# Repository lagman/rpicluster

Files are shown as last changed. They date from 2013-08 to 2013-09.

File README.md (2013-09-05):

RPiCluster Repository
========================================================================================
8-13-2013

Joshua Kiepert  
Boise State University  
Department of Electrical and Computer Engineering  
joshkiepert@boisestate.edu

Overview
----------------------------------------------------------------------------------------
The RPiCluster project was started in Spring 2013 in response to a need during my PhD
dissertation research. My research is currently focused on developing a novel data sharing system
for wireless sensor networks to facilitate in-network collaborative processing of sensor data. 
In the process of developing this system it became clear that perhaps the most expedient way to 
test many of the ideas was to create a distributed simulation rather than developing directly 
on the final target embedded hardware. Thus, I began developing a distributed simulation in which 
each simulation node would behave like a wireless sensor node (along with inherent communications 
limitations), and as such, interact with all other simulation nodes within a LAN. This approach 
provided true asynchronous behavior and actual network communication between nodes which enabled 
better emulation of real wireless sensor network behavior.

So, why I would want to build a Beowulf cluster using Raspberry Pis? The Raspberry Pi has a 
relatively slow CPU by modern standards. It has limited RAM, slow USB-based 10/100 Ethernet, and 
its operating system runs directly on a SD card. None of these “features” are ideal for a cluster 
computer! Well, there are several reasons. First, when your dissertation work requires the use of 
a cluster it is nice to ensure that there is one available all the time. Second, RPis provide a 
unique feature in that they have external low-level hardware interfaces for embedded systems use, 
such as I2 C, SPI, UART, and GPIO. This is very useful to electrical engineers (like myself) 
requiring testing of embedded hardware on a large scale. Third, having user-only access to a 
cluster (which is the case for most student-accessible systems) is fine if the cluster has all 
the necessary tools installed. If not however, you must then work with the cluster administrator 
to get things working. Thus, by building my own cluster I could directly outfit it with anything 
I might need. Finally, RPis are cheap! The RPi platform has to be one of the cheapest ways to 
create a cluster of 32 nodes. The cost for an RPi with an 8GB SD card is ~$45. For comparison, 
each node in one of the clusters available to students here at BSU, was about $1,250. So, for not 
much more than the price of one PC-based node, I could create a 32 node Raspberry Pi
cluster!

Update:
While the BeagleBone Black was not available when I started this project, I would have chosen it 
rather than the Raspberry Pi had it been available. It is the same cost once you include an SD 
card, but it has onboard 2GB of flash storage for the operating system. It also uses a 
Cortex-A8 ARM processor running at 1GHz.

This repository contains the EagleCAD v5.x design files, MPI test code, C test code, and
Bash scripts I used for developing and testing the RPiCluster. 

Documentation
-----------------------
+ docs/Creating.a.Raspberry.Pi-Based.Beowulf.Cluster[BSU].pdf  
	Original white paper on the development of the RPiCluster.

+ docs/Creating.a.Raspberry.Pi-Based.Beowulf.Cluster[EEWeb].pdf  
	Shorter article written for EEWeb's Pulse Magazine  
	http://www.eeweb.com/pulse/issue-106-2013

EagleCAD v5.x Resources
-----------------------
+ eagle/power-led  
	PCB layout for RPiCluster power/led boards
+ eagle/case-layout  
	Plexiglas panel layout (panel measurements, hole patterns, etc)

C Resources
-----------------------
+ c/blink  
	C program that utilizes the wiringPi library to drive the RGB LED on the Power/LED board.

MPI Resources
-----------------------
+ mpi/pblink  
	C MPI program that blinks the RGB LEDs in various patterns on the RPiCluster.

Bash Script Resources
-----------------------
+ scripts/cexec  
	Executes a program on multiple machines via SSH
+ scripts/cscp  
	Copies a local file to multiple machines via SSH
+ scripts/cshutdown  
	Powers down multiple machines via SSH
+ scripts/cssh-copy-id  
	Copies SSH identity to multiple machines for passwordless SSH
+ scripts/rgb-blink  
	Blinks the RGB LEDs on the Power/LED board (using file I/O)
+ scripts/rpitemp  
	Gets the RPi's SoC temperature
+ ssh-everywhere.sh  
	Handy script for creating an SSH session on many machines using tmux

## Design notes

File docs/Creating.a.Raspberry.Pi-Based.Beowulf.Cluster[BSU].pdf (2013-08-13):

# Creating a Raspberry Pi-Based Beowulf Cluster

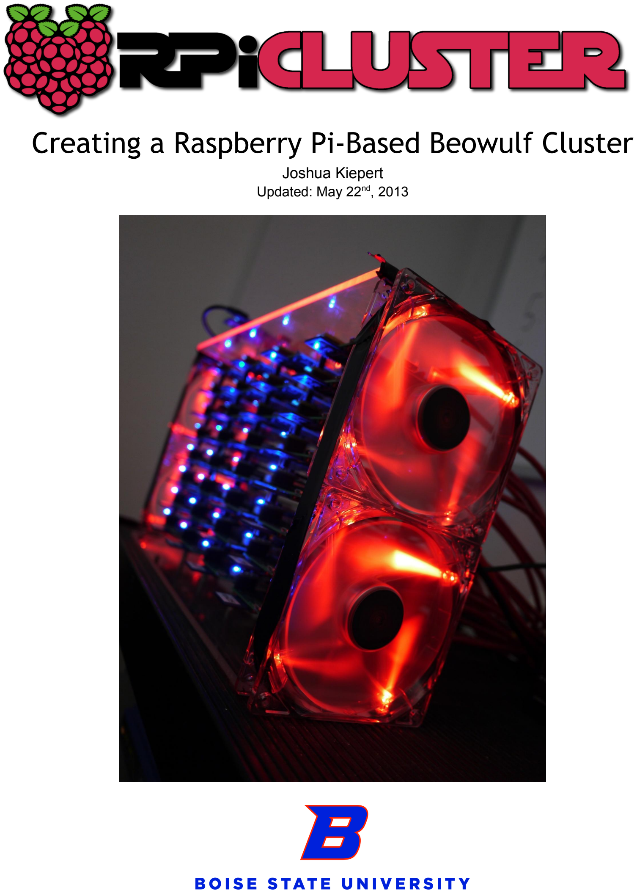
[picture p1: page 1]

Joshua Kiepert
Updated: May 22nd, 2013

## Introduction

Raspberry Pis have really taken the embedded Linux community by storm. For those unfamiliar, however, a Raspberry Pi (RPi) is a small (credit card sized), inexpensive single-board computer that is capable of running Linux and other lightweight operating systems which run on ARM processors. Figure 1 shows a few details on the RPi capabilities.

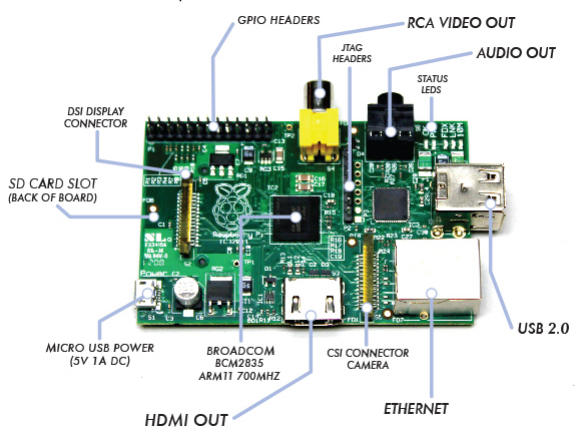
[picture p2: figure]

Figure 1: Raspberry Pi Model B (512MB RAM)

The RPiCluster project was started a couple months ago in response to a need during my PhD dissertation research. My research is currently focused on developing a novel data sharing system for wireless sensor networks to facilitate in-network collaborative processing of sensor data. In the process of developing this system it became clear that perhaps the most expedient way to test many of the ideas was to create a distributed simulation rather than developing directly on the final target embedded hardware. Thus, I began developing a distributed simulation in which each simulation node would behave like a wireless sensor node (along with inherent communications limitations), and as such, interact with all other simulation nodes within a LAN. This approach provided true asynchronous behavior and actual network communication between nodes which enabled better emulation of real wireless sensor network behavior.

For those who may not have heard of a Beowulf cluster before, a Beowulf cluster is simply a collection of identical, (typically) commodity computer hardware based systems, networked together and running some kind of parallel processing software that allows each node in the cluster to share data and computation. Typically, the parallel programming software is MPI (Message Passing Interface), which utilizes TCP/IP along with some libraries to allow programmers to create parallel programs that can split a task into parts suitable to run on multiple machines simultaneously. MPI provides an API that enables both asynchronous and synchronous process interaction. While my simulation did not necessarily need a Beowulf cluster, since it simply required a number of computers on a common network, a cluster environment provided a very convenient development platform for my project thanks to its common file system and uniform hardware.

Here at Boise State University we have such a cluster in the “MetaGeek Lab” (or Onyx Lab), which is run by the Computer Science Department. The Onyx cluster currently utilizes 32 nodes, each of which has an 3.1GHz Intel Xeon E3-1225 quad-core processor and 8GB of RAM. Clearly, this setup has the potential to offer quite good performance for parallel processing.

So, with Onyx available to me, you may ask why I would build a Beowulf cluster using Raspberry Pis? Well, there are several reasons. First, while the Onyx cluster has an excellent uptime rating, it could be taken down for any number of reasons. When you have a project that requires the use of such a cluster and Onyx is unavailable, there are not really any other options on campus available to students aside from waiting for it to become available again. The RPiCluster provides another option for continuing development of projects that require MPI or Java in a cluster environment. Second, RPis provide a unique feature in that they have external low-level hardware interfaces for embedded systems use, such as I²C, SPI, UART, and GPIO. This is very useful to electrical engineers requiring testing of embedded hardware on a large scale. Third, having user only access to a cluster is fine if the cluster has all the necessary tools installed. If not however, you must then work with the cluster administrator to get things working. Thus, by building my own cluster I could outfit it with anything I might need directly. Finally, RPis are cheap! The RPi platform has to be one of the cheapest ways to create a cluster of 32 nodes. The cost for an RPi with an 8GB SD card is ~$45. For comparison, each node in the Onyx cluster was somewhere between $1,000 and $1,500. So, for near the price of one PC-based node, we can create a 32 node Raspberry Pi cluster!

Although an inexpensive bill of materials looks great on paper, cheaper parts come with their own set of downsides. Perhaps the biggest downside is that an RPi is no where near as powerful as a current x86 PC. The RPi has a single-core ARM1176 (ARMv6) processor, running at 700MHz (though overclocking is supported). Additionally, since the RPi uses an ARM processor, it has a different architecture than PCs, i.e. ARM vs x86. Thus, any MPI program created originally on x86 must be recompiled when deployed to the RPiCluster. Fortunately, this issue is not present for java, python, or perl programs. Finally, because of the limited processing capability, the RPiCluster will not support multiple users simultaneously using the system very well. As such, it would be necessary to create some kind of time-sharing system for access if it ever needed to be used in such a capacity.

The overall value proposition is pretty good, particularly if cluster program development is focused on distributed computing rather than parallel processing. That is, if the programs being developed for the cluster are distributed in nature, but not terribly CPU intensive. Compute-intensive applications will need to look elsewhere, as there simply is not enough “horse power” available to make the RPi a terribly useful choice for cluster computing.

## Building the System

There are really only five major components needed for a working cluster: computer hardware, Linux OS, an MPI library, an ethernet switch, and possibly a router. Of course, we have already chosen the

RPi as the computer hardware. Figure 2 (a) shows the overall network architecture. The system design includes 32 RPi nodes, 48-port 10/100 switch, Arch Linux ARM, and MPICH3. The bill of materials can be seen in Figure 2 (b).

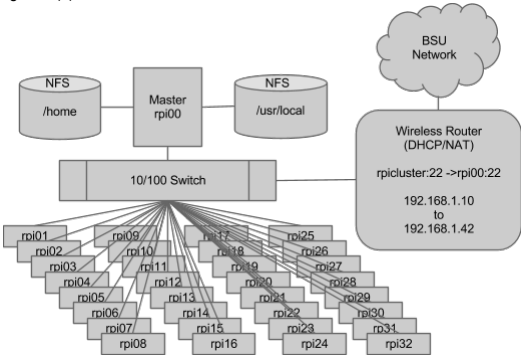
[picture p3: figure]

(a) RPiCluster Network Architecture

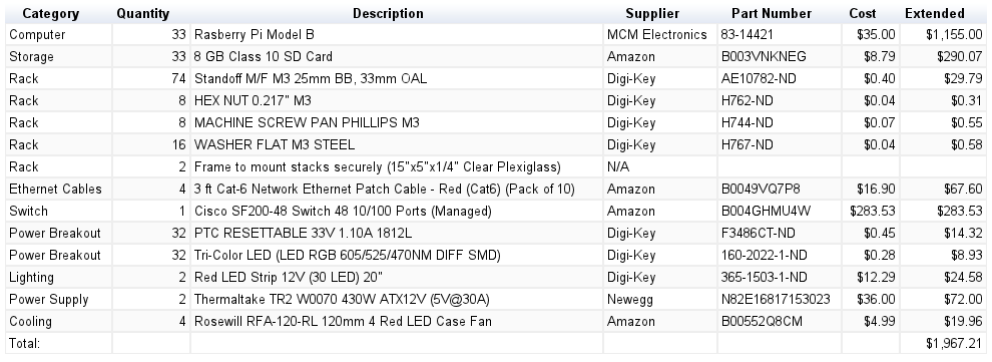
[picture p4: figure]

(b) Bill of Materials
Figure 2: Cluster Design

There are several operating systems available as pre-configured Linux images for the RPi: Raspbian “wheezy” (based on Ubuntu 11.10) and Arch Linux for ARM (aka “alarm”) ( raspberrypi (http://www.raspberrypi.org/downloads). (http://www.raspberrypi.org/downloads) org). (http://www.raspberrypi.org/downloads) Raspbian is available in both hard and soft float versions. “Hard-float” implies it is compiled with support for the hardware floating-point unit in the ARM processor, whereas soft-float implies it will use software libraries to implement floating-point operations. Clearly, hard float is desirable for performance, but for compatibility reasons soft-float is available. In the case of Raspbian, hard-float is not yet supported by

Oracle’s Java Development Kit (JDK)/Java Virtual Machine (JVM) for ARM. It is worth noting that the Oracle JDK is not the only Java implementation available, so there is no need to limit performance with soft-float. The beauty of open source is that you can simply compile the program for your platform even if the vendor has not taken the time to do so. In this case, OpenJDK (http://openjdk.java.net/) is the open source implementation of Java, and it is available on all Linux distributions, including Raspbian and Arch. Arch LInux for ARM is only available in the hard-float configuration.

So, which Linux distribution makes sense for a cluster of RPis? This depends greatly on how comfortable you are with Linux. Raspbian provides a turnkey solution in that it comes pre-installed with the LXDE (a full desktop environment), and being Debian based, there is a huge set of packages precompiled and available for the RPi. This is great for getting started with Linux and with the RPi in general. The downside to this distribution is its weight. With support for so many features to begin with, there is a staggering amount of daemons running all the time. As such, boot time is much longer than it has to be, and you have many packages installed that you most likely will never need or use.

Arch LInux on the other hand, takes the minimalist approach. The image is tiny at ~150MB. It boots in around 10 seconds. The install image has nothing extra included. The default installation provides a bare bones, minimal environment, that boots to a command line interface (CLI) with network support. The beauty of this approach is that you can start with the cleanest, fastest setup and only add the things you need for your application. The downside is you have to be willing to wade through the learning process of a different (but elegant) approach to Linux, which is found in Arch Linux. Fortunately, Arch Linux has some of the best organized information out there for learning Linux. An excellent place to start is the Arch (https://wiki.archlinux.org/index.php/Beginners'_Guide) Linux (https://wiki.archlinux.org/index.php/Beginners'_Guide) Beginner (https://wiki.archlinux.org/index.php/Beginners'_Guide)’ (https://wiki.archlinux.org/index.php/Beginners'_Guide) s (https://wiki.archlinux.org/index.php/Beginners'_Guide) Guide. (https://wiki.archlinux.org/index.php/Beginners'_Guide) I could go on about all the things I appreciate about Arch Linux, but I digress. As you might have guessed from my previous statements, and being a “Linux guy” myself (Linux Mint, primarily), I chose Arch Linux for the RPiCluster.

As for the MPI implementation, I chose MPICH primarily due to my previous familiarity with it through Parallel Computing classes (OpenMPI is available also). If you are running Raspbian, MPI can be installed by executing something like:

$ sudo apt-get install mpich2

That’s it. However, on Arch Linux MPICH must be compiled from source, or installed from the AUR database. I did some looking on AUR, and only found an older version of MPICH (built for an old version of gcc). So, I went with the compile-from-source method. You can get the source from mpich (http://www.mpich.org/downloads/). (http://www.mpich.org/downloads/) org. (http://www.mpich.org/downloads/) OpenMPI is available in the Arch Linux repositories, and it can be installed as follows:

$ sudo pacman -Syy openmpi

In the case of MPICH, compiling large amounts of source on a 700MHz machine can be tedious. So, why not utilize our Core i7 Quad-Core to do the job? Enter: QEMU. QEMU (http://en.wikibooks.org/wiki/QEMU) is a CPU architecture emulator and virtualization tool. It so happens that it is capable of emulating an ARM architecture very similar to the RPi. This allows us to boot an RPi image directly on our x86 or x86_64 system! There is one caveat, you need an RPI kernel for QEMU that knows how to deal with the QEMU virtualized hardware which is not normally part of the RPi kernel image. This involves downloading the Linux kernel source, applying a patch to support the RPi, adding the various kernel features and drivers needed, and compiling. The compile process for the kernel only took about 5 minutes on my i7 laptop. Downloading the source from the Git repository, however, took much longer (~1.5GB).

There are several tutorials available which provide details for running QEMU with an RPI system image. A couple references I found useful are Raspberry (http://www.v13.gr/blog/?p=276) Pi (http://www.v13.gr/blog/?p=276) under (http://www.v13.gr/blog/?p=276) QEMU (http://www.v13.gr/blog/?p=276) and Raspberry (http://ebalaskas.gr/blog/2013/03/25/raspberry-pi-with-archlinux-under-qemu/) Pi (http://ebalaskas.gr/blog/2013/03/25/raspberry-pi-with-archlinux-under-qemu/) with Archlinux (http://ebalaskas.gr/blog/2013/03/25/raspberry-pi-with-archlinux-under-qemu/) under (http://ebalaskas.gr/blog/2013/03/25/raspberry-pi-with-archlinux-under-qemu/) QEMU. (http://ebalaskas.gr/blog/2013/03/25/raspberry-pi-with-archlinux-under-qemu/) Aside from the need for a custom kernel, there are a couple system configuration changes needed within the RPi image to allow it to boot flawlessly. The changes primarily have to do with the fact that the RPi images assume the root file system is on /dev/mmcblk0p2 and the boot partition is on /dev/mmcblk0p1. QEMU makes no such assumptions so you have to map /dev/sda devices to mmcblk0 devices on boot. With the RPi system image adjusted and the custom kernel built, starting QEMU is something like the following:

$ qemu-system-arm -kernel ./zImage -cpu arm1176 -m 256 -M versatilepb -no-reboot -serial stdio -append "root=/dev/sda2 panic=0 rw" -hda archlinux-hf-2013-02-11.img

Once you have a kernel image (zImage) that is suitable for QEMU you can point it at the new kernel and the RPi system image. Running an RPi image via QEMU may be significantly faster than working on the RPi, of course, this depends on the computer being used to run QEMU. Figure 3 shows the boot screen of Arch Linux ARM under QEMU.

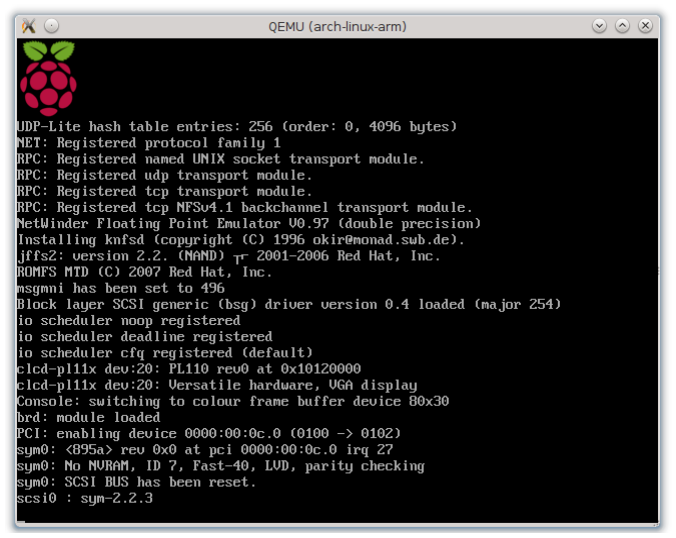
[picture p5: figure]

Figure 3: Arch Linux ARM under QEMU

With a working Arch Linux image under QEMU it is possible to update to the latest packages, install the necessary packages for the cluster environment, and compile MPICH for parallel computing, all from the comfort of you x86 Linux system. I used QEMU for all of the aforementioned tasks. Once configuration of the image was completed with QEMU, I was able to simply write the resulting image to each RPi SD card (after modifying hostname and IP address, unique to each).

Below are a few of the steps involved for configuring an Arch Linux image for use in a cluster:

Change root password from default (root):
# passwd

Full system update:
# pacman -Syyu

Install typically needed packages, bold packages are need for compiling MPICH and for using NFS or OpenMPI:
# pacman -S nfs-utils | base-devel | openmpi | sudo | adduser | nano vim | gdb | bc | minicom

Set | the | local | timezone:
# | timedatectl | set-timezone | | America/Boise

Adds a new user...<user> in this case (be sure to add groups wheel,audio,video,uucp when prompted):
# | adduser | <user>

Allow users that are part of the wheel group to use superuser permissions:
# | chmod | 600 /etc/sudoers

# | nano | /etc/sudoers

(Uncomment the line: %wheel = ... and save)

# logout

(Login as user who will be using MPI)
$ | ssh-keygen | -t | rsa
$ | ssh-keygen | -t | dsa
$ | ssh-keygen | -t | edsa

Cluster setup is basically just configuring a few files so that all nodes can find each other and have password-less SSH access to one another.

Key configuration files for cluster setup under Arch Linux:
/etc/exports
/etc/idmapd.conf
/etc/hosts
/etc/hostname
/etc/fstab
/etc/network.d/ethernet-static /etc/conf.d/netcfg

## Performance Comparison

Initially, I created a four-node test platform with RPis. So, it was possible to do some preliminary testing of performance before creating the full cluster. The first test was to determine the general performance of a single node running multiple threads, using the MPI libraries.

The MPI test program I used is one I developed during a parallel computing class at BSU. The program calculates pi using the Monte (http://en.wikipedia.org/wiki/Pi#Geometry_and_trigonometry) Carlo (http://en.wikipedia.org/wiki/Pi#Geometry_and_trigonometry) method. In this method, essentially the more random numbers you generate, the more accurate your resulting estimation of pi. It is an embarrassingly parallel way to calculate pi (i.e., scales easily to multiple independent processes, near 100% performance gain for each additional process added). All that is needed is a way to parallelize the generation of random numbers so that each process does not repeat the random sequence (remember, we are dealing with pseudorandom numbers here). In this case, I use a library called prand, (http://cs.boisestate.edu/~amit/research/prand/) developed by Dr. Jain and Jason Main at BSU.

Table 1 shows the hardware specifications of the various platforms tested for comparison.

Table 1: Test Hardware Specifications

Figure 4 shows the execution time for 900 Million iterations of the Monte Carlo pi calculation program (PMCPI).

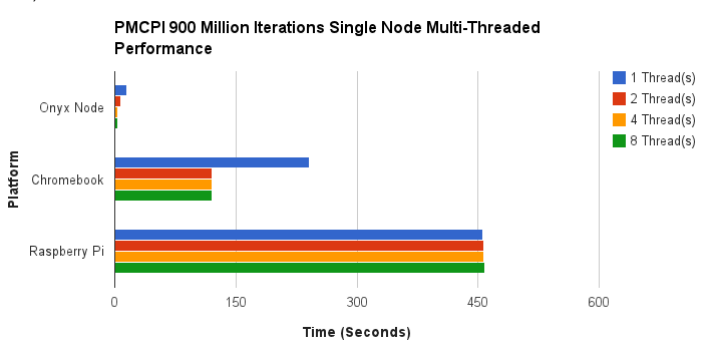
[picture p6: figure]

Figure 4: MPI Single Node Performance¹

1 This is running the MPI program on a single node with multiple threads, not in parallel with other nodes in a cluster.

If you can not tell from Figure 4, that is a maximum of 14.6 seconds for a single thread on an Onyx node. With four threads it goes down to 3.85 seconds thanks to four processing cores. With eight threads, it goes up to 3.90 seconds. Compare that to our lowly RPi, which requires 456 seconds for single thread. Additional threads do not help due to its single core design.

Figures 5 and 6 show the performance improvement as we add additional RPi nodes to participate in the calculation, in execution time and speed up, respectively.

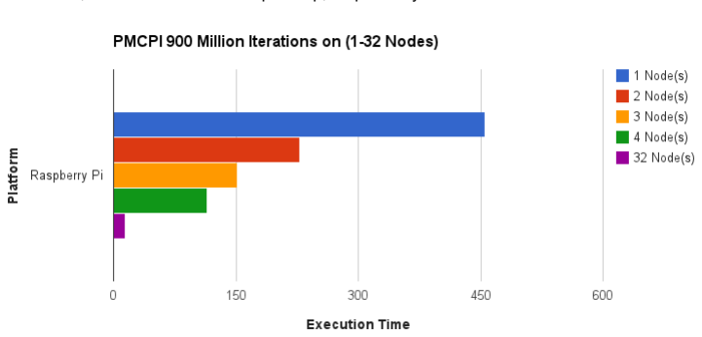
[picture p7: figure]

Figure 5: Execution Time Reduction (1-32 nodes)

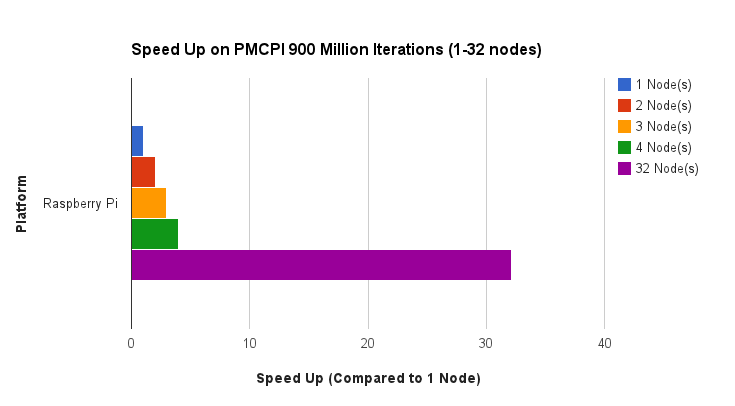
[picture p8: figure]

Figure 6: Speed-Up as Compared to 1 Node

As is seen in Figures 5 and 6, we clearly get the expected performance improvement as we add additional nodes to participate in the calculations.

## Rack and Power Design

One aspect of the cluster design that required quite a lot of thought was the rack mounting system and power distribution method. In order to keep the cluster size to a minimum while maintaining ease of access, the RPis were stacked in groups of eight using PCB-to-PCB standoffs with enough room in between them for a reasonable amount of air flow and component clearance. This configuration suited our needs for power distribution very well since it allowed for a power line to be passed vertically along each stack. Using this orientation, four RPi stacks were assembled and mounted between two pieces of ¼” acrylic. This created a solid structure in which the cluster could be housed and maintain physical stability under the combined weight of 32 Ethernet cables. Figure 7 (a) shows some initial experimentation using this method of mounting. The plexiglass layout for mounting each RPi stack was designed using EagleCAD, along with the power/LED PCB. Figure 7 (b) shows the layout.

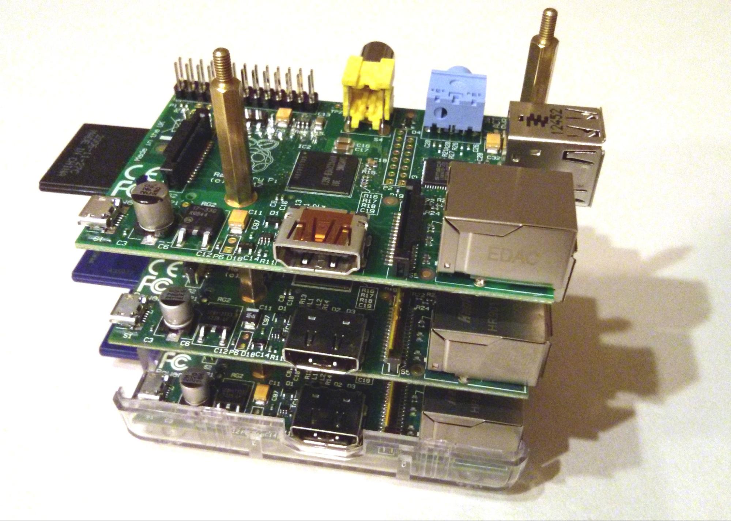
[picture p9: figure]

(a) Rack Mounting RPis Using PCB Stand-offs

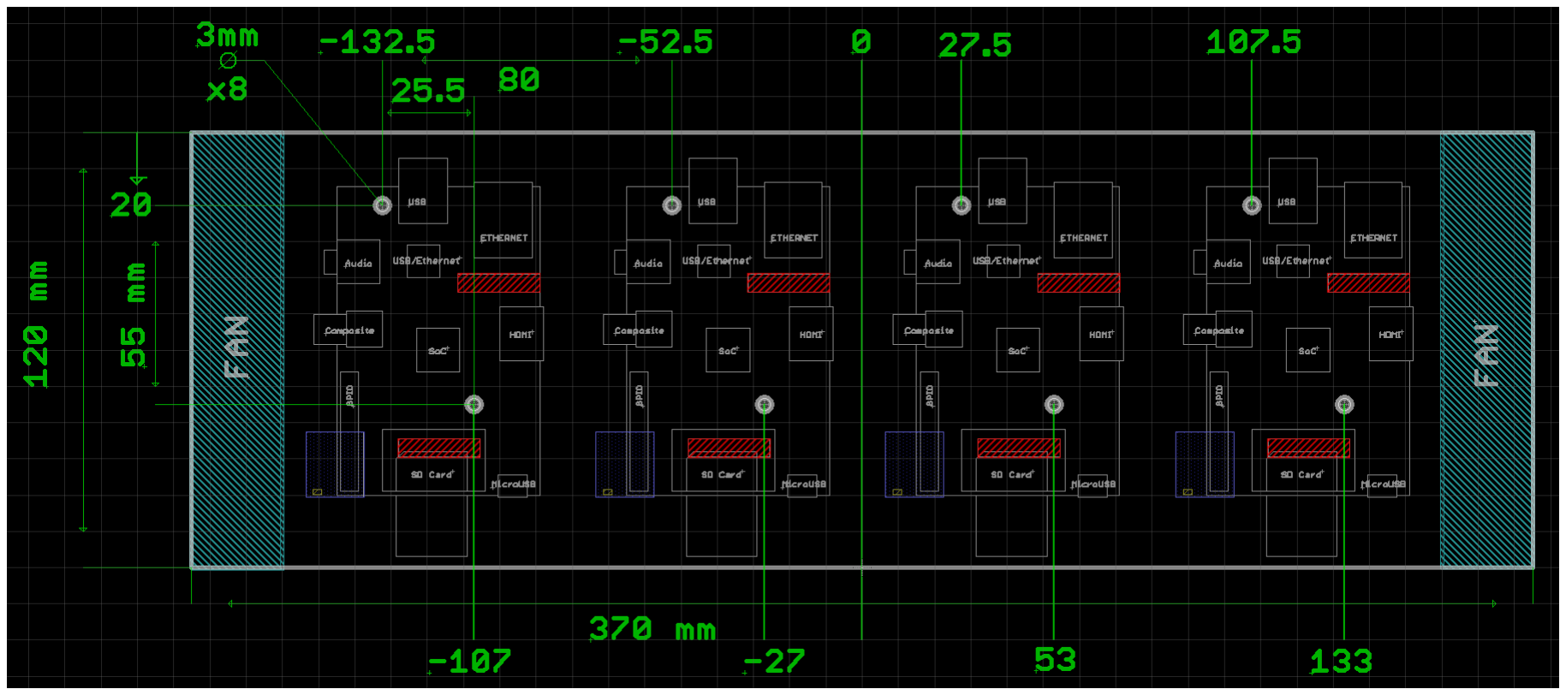
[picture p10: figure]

(b) Plexiglass Layout (Top/Bottom of RPiCluster Rack) Figure 7: RPiCluster Rack Components

There are two methods of powering an RPi. Each RPi has a microUSB port that enables it to be powered from a conventional powered USB port. Using this method would require a microUSB cable and a powered USB port for every RPi in the cluster, which would add a lot more cabling to deal with. It also means that there would be cabling on both sides of the cluster. Alternatively, there is an I/O header on the side of the RPi which contains a 5V pin that can be used to power the board externally. The latter option was chosen as it would also allow for additional customization and control of each node. A custom PCB was created to fit the I/O header to provide power and an RGB LED (since electrical engineers must, of course, have LEDs to show that their project is working). Figure 8 (a) and (b) show the circuit and PCB layouts, respectively.

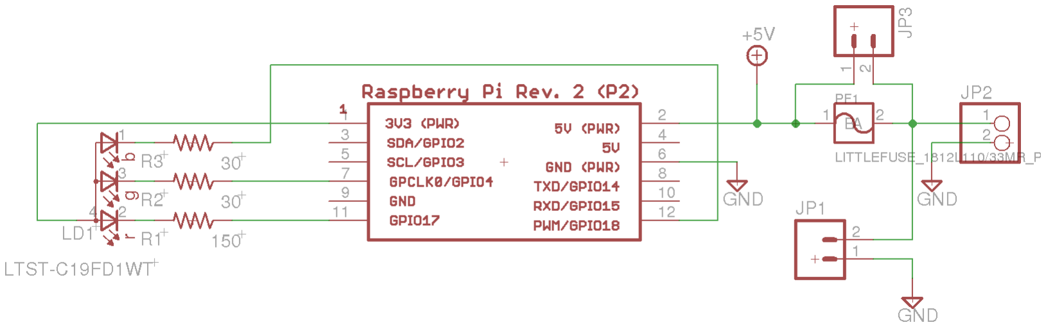
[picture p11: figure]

(a) RPiCluster Power/LED Board Schematic

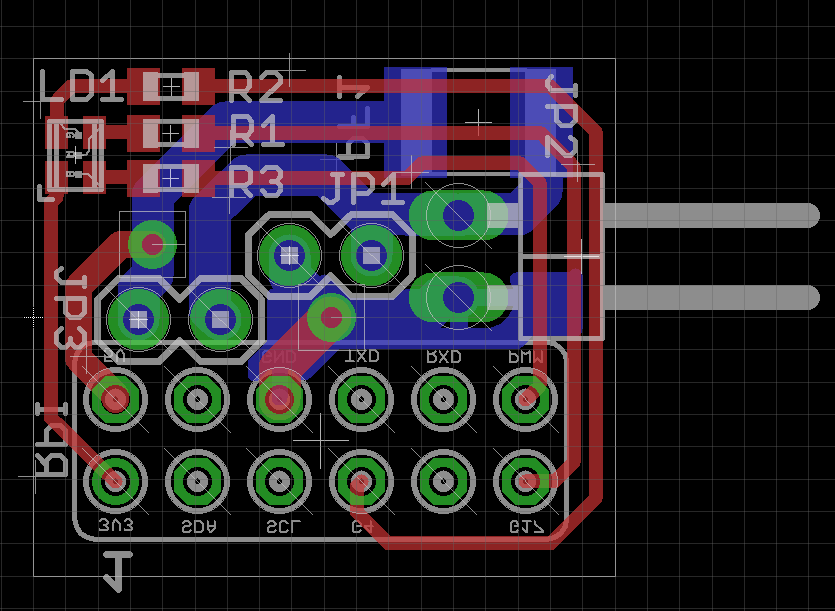
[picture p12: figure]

(b) RPiCluster Power/LED Board PCB Layout Figure 8: RPiCluster Power/LED Board

As seen in Figure 8 (a), aside from a RGB LED and some connectors, there is also a poly fuse (PF1). This was included to maintain short-circuit protection in the event of a board failure. The RPi already has a poly fuse between the USB power connector and the 5V rail. That fuse is bypassed when using the 5V pin to power the board. JP1 provides a 5V interconnect vertically between the RPis in each stack.

With the power being directly distributed via the Power/LED board, it was necessary to find a good source of 5V with sufficient amperage to drive the whole cluster. Each RPi draws about 400mA at 5V (2W), thus we needed a minimum of 13A of 5V (65W) (and more for overclocking). You could, of course, buy a dedicated high output 5V power supply, but a great option is to use a standard PC power supply. PC power supplies are already designed for high loads on their 5V rails, and they are relatively cheap. The 430W Thermaltake (430W combined output for 5V, 12V, etc) we selected is rated to provide 30A at 5V (150W) and cost $36. We opted to purchase two supplies to keep the overall load very low on each and allow for overclocking or future expansion.

## Final Tweaks

As mentioned earlier, the RPi processor supports overclocking. Another noteworthy feature is that the 512MB of RAM is shared by both GPU and CPU, and the amount of RAM reserved for the GPU is configurable. Both of these features are configurable through modification of parameters in /boot/config.txt. After some testing, the whole cluster was set to run in “Turbo Mode” which overclocks the ARM core to 1GHz and sets the other clocks (SDRAM etc..) to 500MHz. The result was a proportional increase in performance (~30%) and power draw. Since the cluster does not require a desktop environment, the GPU RAM reserve was reduced to 48MB. 48MB seems to be the smallest amount of RAM allowed for the GPU on the current version of Arch Linux ARM for the RPi (it wouldn’t boot with anything less).

## Power Consumption

One of the great things about creating a cluster with ARM-based processors is low power consumption. As discussed earlier, each RPi uses about 2W of power (when running at 700MHz). A number of power measurements were made at the wall with the RPiCluster in various operational states. This allowed the individual component power usage to be determined without taking each item off-line to measure power draw individually. As I have overclocked the cluster to 1GHz core frequency and 500MHz for SDRAM etc., the power consumption is higher. Figures 9 (a) and (b) show the overall power use (as measured at the wall) in relative proportion (percent) and watts, respectively (overclocked to 1GHz).

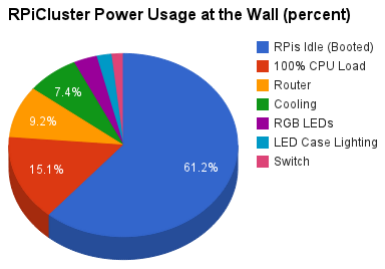
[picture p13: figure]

(a) RPiCluster Component Power Useage (percent)

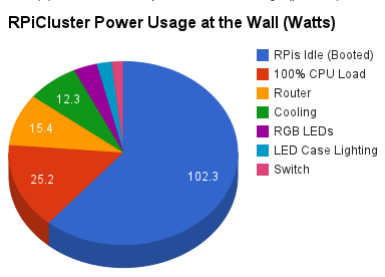
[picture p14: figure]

(b) RPiCluster Component Power Usage (Watts) Figure 9: RPiCluster Power Consumption

As is seen in Figure 9 (b), there is about 15% difference in power consumption between idle and full CPU utilization. Additionally, about 12% of the total power used is attributed to the cooling portion of the cluster (four 120mm fans). The maximum total power usage of the cluster at the wall is about 167

Watts. It is worth noting that active cooling is technically unnecessary. During my testing, the SoC temperature did not exceed 60° C while under 100% load, and the SoC is rated to operate up to 85° C. With cooling active, however, the SoC temperatures did not exceed 35° C. Cooling was retained because it seemed better for the SoC to operate at lower temperatures (and it looks nice).

## Conclusion

Overall, the RPiCluster has proved quite successful. Since completing the build I have moved my dissertation work exclusively to the RPiCluster. I have found performance perfectly acceptable for my simulation needs, and have had the luxury of customizing the cluster software to fit my requirements exactly.

I would like to thank all the guys I work with in the Hartman Systems Integration Laboratory for all their help implementing the cluster design, especially Michael Pook, Vikram Patel, and Corey Warner. Additionally, this project would not have been possible without support from Dr. Sin Ming Loo and the Department of Electrical and Computer Engineering.

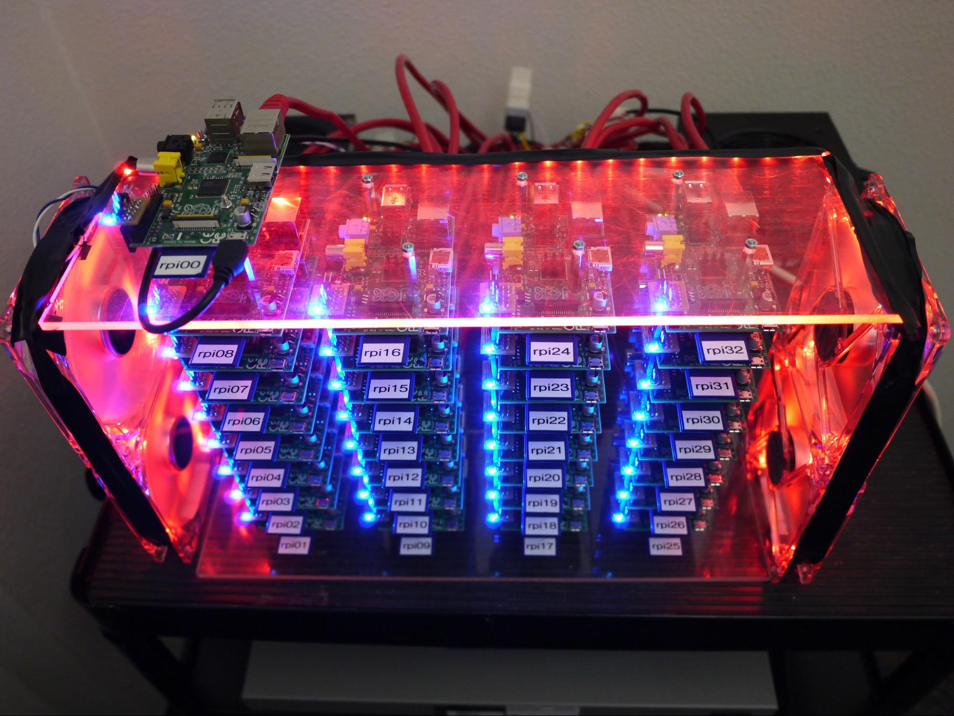
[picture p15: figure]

...and for your viewing pleasure, I have a few more photos:

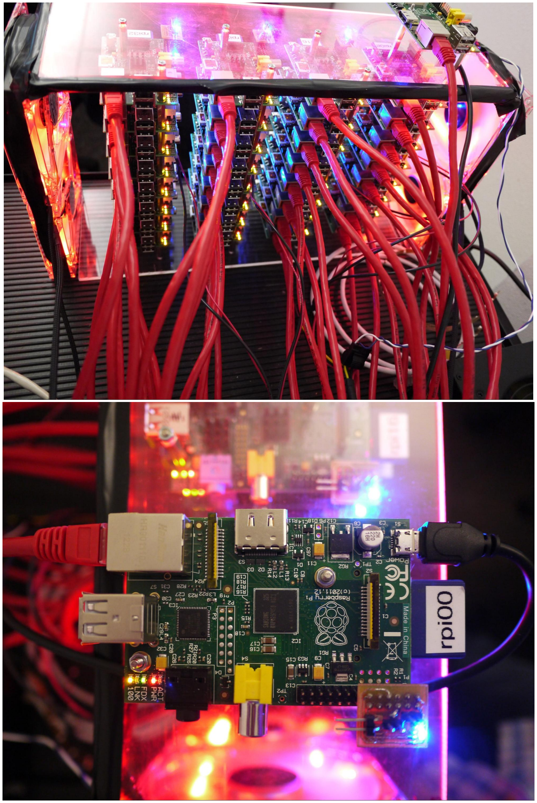
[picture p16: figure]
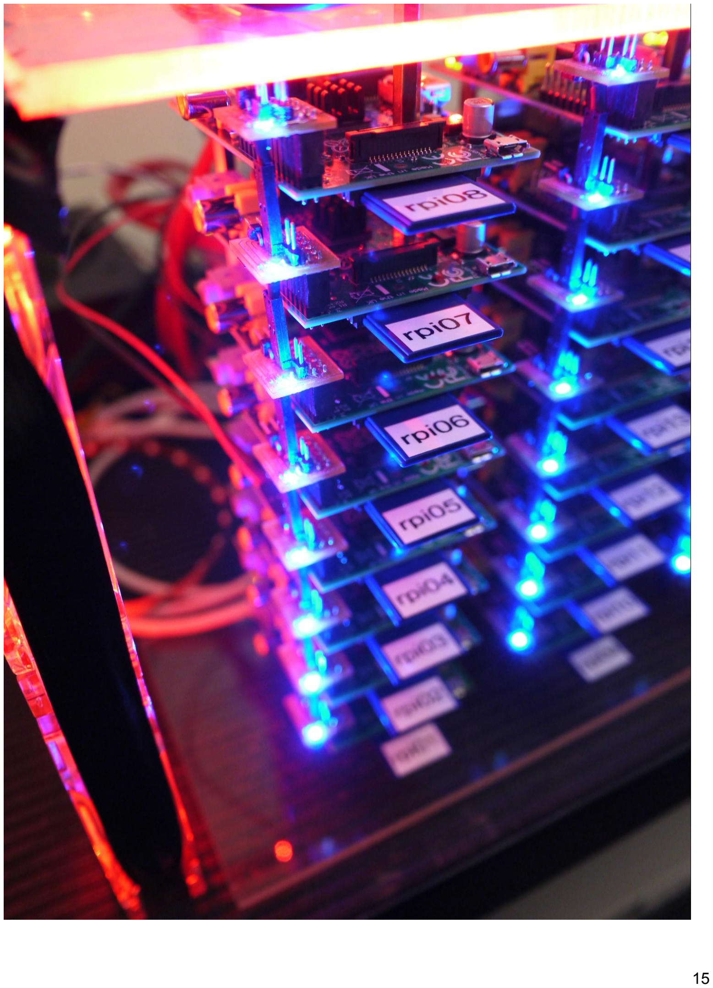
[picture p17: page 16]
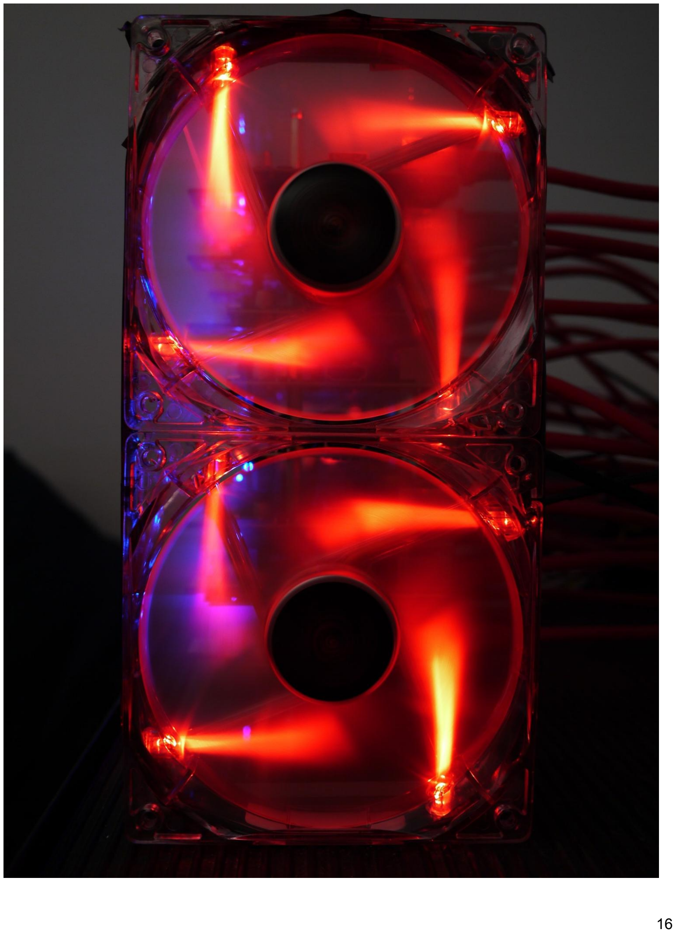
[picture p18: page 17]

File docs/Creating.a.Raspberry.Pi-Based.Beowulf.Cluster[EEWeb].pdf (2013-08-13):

# Creating a Raspberry Pi-Based Beowulf Cluster

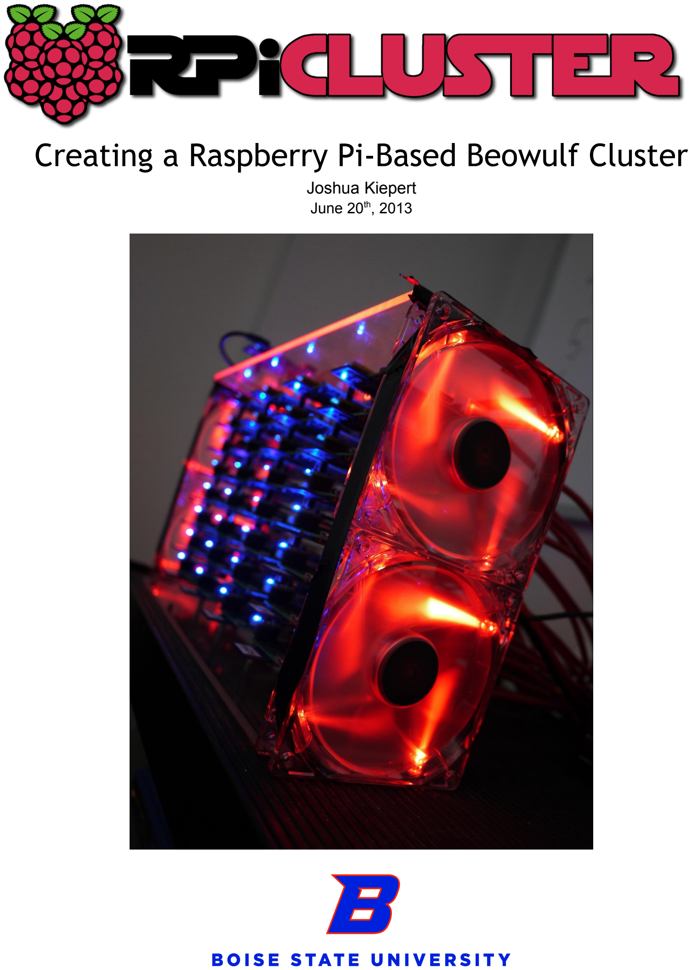
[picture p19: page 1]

Joshua Kiepert
June 20th, 2013

## Introduction

Raspberry Pis have really taken the embedded Linux community by storm. For those unfamiliar, however, a Raspberry Pi (RPi) is a small (credit card sized), inexpensive single-board computer that is capable of running Linux and other lightweight operating systems which run on ARM processors. Figure 1 shows a few details on the RPi's capabilities.
[Figure 1]
The RPiCluster project was started a couple months ago in response to a need during my PhD dissertation research. My research is currently focused on developing a novel data sharing system for wireless sensor networks to facilitate in-network collaborative processing of sensor data. In the process of developing this system it became clear that perhaps the most expedient way to test many of the ideas was to create a distributed simulation rather than developing directly on the final target embedded hardware. Thus, I began developing a distributed simulation in which each simulation node would behave like a wireless sensor node (along with inherent communications limitations), and as such, interact with all other simulation nodes within a LAN. This approach provided true asynchronous behavior and actual network communication between nodes which enabled better emulation of real wireless sensor network behavior.

For those who may not have heard of a Beowulf cluster before, a Beowulf cluster is simply a collection of similar, (typically) commodity computer hardware based systems, networked together and running some kind of parallel processing software that allows each node in the cluster to share data and computation. Typically, the parallel programming software is MPI (Message Passing Interface), which utilizes TCP/IP along with some libraries to allow programmers to create parallel programs that can split a task into parts suitable to run on multiple machines simultaneously. MPI provides an API that enables both asynchronous and synchronous process interaction. My simulation did not require the computational power of a Beowulf cluster; it simply required a many distinct computers on a common network. A cluster environment provided a very convenient development platform for my distributed simulation thanks to its common file system and uniform hardware.

So, why I would want to build a Beowulf cluster using Raspberry Pis? The Raspberry Pi has a relatively slow CPU by modern standards. It has limited RAM, slow USB-based 10/100 Ethernet, and its operating system runs directly on a SD card. None of these “features” are ideal for a cluster computer! Well, there are several reasons. First, when your dissertation work requires the use of a cluster it is nice to ensure that there is one available all the time. Second, RPis provide a unique feature in that they have external low-level hardware interfaces for embedded systems use, such as I²C, SPI, UART, and GPIO. This is very useful to electrical engineers (like myself) requiring testing of embedded hardware on a large scale. Third, having user-only access to a cluster (which is the case for most student-accessible systems) is fine if the cluster has all the necessary tools installed. If not however, you must then work with the cluster administrator to get things working. Thus, by building my own cluster I could directly outfit it with anything I might need. Finally, RPis are cheap! The RPi platform has to be one of the cheapest ways to create a cluster of 32 nodes. The cost for an RPi with an 8GB SD card is ~$45. For comparison, each node in one of the clusters available to students here at BSU, was about $1,250. So, for not much more than the price of one PC-based node, I could create a 32 node Raspberry Pi cluster!

One thing to keep in mind when building a cluster with RPis is to set expectations of performance appropriately. That is, we cannot expect the compute performance to be very good, even when compared to a single modern multi-core desktop computer. This was not a problem for my application because I just needed many independent processors running on a common network to run my distributed application. I didn't need a platform for high performance computing (HPC). Additionally, since the RPi uses an ARM processor, it has a different architecture than PCs, i.e. ARM vs x86. Thus, any MPI program created originally on x86 must be recompiled when deployed to the RPiCluster. Fortunately, this issue is not present for Java, Python, or Perl programs. Finally, because of the limited processing capability, the RPiCluster will not support multiple users simultaneously using the system very well. As such, it would be necessary to create some kind of time-sharing system for access if it ever needed to be used in such a capacity.

In summary, the RPiCluster is great if your development is focused only on distributed computing/network programming rather than parallel processing. That is, if the programs being developed for the cluster are distributed in nature, but not terribly CPU intensive. Compute-intensive applications will need to look elsewhere, as there simply is not enough “horse power” available to make the RPi a terribly useful choice for cluster computing. Of course, even compute-intensive applications could be tested on a small scale with the RPiCluster.

## Building the System

There are really only five major components needed for a working cluster: computer hardware, Linux OS, an MPI library, an Ethernet switch, and possibly a router. Figure 2 shows the overall network architecture. The RPiCluster design consists of 32 RPi nodes, a 48-port 10/100 switch, Arch Linux ARM, and MPICH3. The total cost of the system was $1,967.21.
[Figure 2]
There are several operating systems available as pre-configured Linux images for the RPi: Raspbian “wheezy” (based on Debian) and Arch Linux for ARM (aka “alarm”) ( raspberrypi (http://www.raspberrypi.org/downloads). (http://www.raspberrypi.org/downloads) org). (http://www.raspberrypi.org/downloads) I chose to use Arch Linux for the RPiCluster. Arch Linux was chosen primarily for its minimalist approach which allowed me to install only what I needed. It also resulted in a system that boots in about 10 seconds. There is definitely a learning curve with Arch Linux, but fortunately it has some of the best organized information out there for learning Linux. An excellent place to start is the Arch (https://wiki.archlinux.org/index.php/Beginners'_Guide) Linux (https://wiki.archlinux.org/index.php/Beginners'_Guide) Beginner (https://wiki.archlinux.org/index.php/Beginners'_Guide)’ (https://wiki.archlinux.org/index.php/Beginners'_Guide) s (https://wiki.archlinux.org/index.php/Beginners'_Guide) Guide. (https://wiki.archlinux.org/index.php/Beginners'_Guide)

As for an MPI implementation, I chose MPICH primarily due to my previous familiarity with it (OpenMPI is also available). On Arch Linux MPICH must be compiled from source, or installed from the Arch User Repository (AUR). I went with the compile-from-source method. You can get the source from
mpich (http://www.mpich.org/downloads/). (http://www.mpich.org/downloads/) org. (http://www.mpich.org/downloads/) OpenMPI is available directly in the Arch Linux extra repository.

One thing I found helpful when creating an Arch Linux image for the RPiCluster was QEMU. QEMU (http://en.wikibooks.org/wiki/QEMU) is a CPU architecture emulator and virtualization tool. It is capable of emulating an ARM architecture similar to the RPi. This allows us to boot an RPi image directly on our x86 system. There is one caveat: you need an RPI kernel for QEMU that knows how to deal with the QEMU virtualized hardware, which is not normally part of the RPi kernel image. This involves downloading the Linux kernel source, applying a patch to support the RPi, adding the various kernel features and drivers needed, and compiling.

There are several tutorials available which provide details for running QEMU with an RPI system image. A couple references I found useful are Raspberry (http://www.v13.gr/blog/?p=276) Pi (http://www.v13.gr/blog/?p=276) under (http://www.v13.gr/blog/?p=276) QEMU (http://www.v13.gr/blog/?p=276) and Raspberry (http://ebalaskas.gr/blog/2013/03/25/raspberry-pi-with-archlinux-under-qemu/) Pi (http://ebalaskas.gr/blog/2013/03/25/raspberry-pi-with-archlinux-under-qemu/) with (http://ebalaskas.gr/blog/2013/03/25/raspberry-pi-with-archlinux-under-qemu/)

Archlinux (http://ebalaskas.gr/blog/2013/03/25/raspberry-pi-with-archlinux-under-qemu/) under (http://ebalaskas.gr/blog/2013/03/25/raspberry-pi-with-archlinux-under-qemu/) QEMU. (http://ebalaskas.gr/blog/2013/03/25/raspberry-pi-with-archlinux-under-qemu/) Aside from the need for a custom kernel, there are a couple system configuration changes needed within the RPi image to allow it to boot flawlessly. The changes primarily have to do with the fact that RPi images assume the root file system is on /dev/mmcblk0p2 and the boot partition is on /dev/mmcblk0p1. QEMU makes no such assumptions so you have to map /dev/sda devices to mmcblk0 devices on boot. With the RPi system image adjusted and the custom kernel built, starting QEMU is something like the following:

$ qemu-system-arm -kernel ./zImage -cpu arm1176 -m 256 -M versatilepb -no-reboot -serial stdio -append "root=/dev/sda2 panic=0 rw" -hda archlinux-hf-2013-02-11.img

Once you have a kernel image (zImage) that is suitable for QEMU you can point it at the new kernel and the RPi system image. Figure 3 shows the boot screen of Arch Linux ARM under QEMU. [Figure 3]
With a working Arch Linux image under QEMU, I applied system updates and installed the necessary packages for the cluster environment. Once configuration of the image was completed with QEMU, I was able to simply write the resulting image to each RPi SD card after modifying host name and static IP address, unique to each (I wrote a bash script to do this).

Below are a few of the steps involved for configuring an Arch Linux image for use in a cluster:

1. Change root password from default (root):
# passwd

2. Full system update:
# pacman -Syyu

3. Install typically needed packages, (bold packages are need for using NFS, OpenMPI, and software development:
# pacman -Syy nfs-utils | base-devel | openmpi | sudo | adduser gdb

4. Set the timezone for your location (<city>):
# timedatectl set-timezone America/<city>

5. Add a new user (<user>) and be sure to add groups wheel, audio, video, and uucp when prompted:
# adduser <user>

6. Allow users that are part of the wheel group to use superuser permissions:
# chmod 600 /etc/sudoers

7. Uncomment the line: %wheel = ... and save:
# nano /etc/sudoers

8. Logout of root and login as the user who will be using MPI and generate ssh keys for password-less login:
$ | ssh-keygen | -t | rsa
$ | ssh-keygen | -t | dsa
$ | ssh-keygen | -t | edsa

Strictly speaking, there is nothing special needed for a working cluster other than MPI and SSH, however a shared file system makes life much easier (e.g. NFS). Cluster setup is basically just configuring a few files so that all nodes can find each other by name on the network and have password-less SSH access to one another. Key configuration files for cluster setup under Arch Linux:

NFS: | /etc/exports
NFS: | /etc/idmapd.conf
NFS: | /etc/fstab
SSH: | /home/<mpiuser>/.ssh/authorized_keys
Network: | /etc/hosts
Network: | /etc/hostname
Network: | /etc/network.d/ethernet-static
Network: | /etc/conf.d/netcfg

For the fine details on NFS, network, and SSH setup, see the Arch Wiki: NFS, (https://wiki.archlinux.org/index.php/NFS) Network, (https://wiki.archlinux.org/index.php/Beginners'_Guide#Static_IP) SSH. (https://wiki.archlinux.org/index.php/SSH_Keys)
Rack and Power Design
One aspect of the cluster design that required quite a lot of thought was the rack mounting system and power distribution method. In order to keep the cluster size to a minimum while maintaining ease of access, the RPis were stacked in groups of eight using PCB-to-PCB standoffs with enough room in between them for a reasonable amount of air flow and component clearance. This configuration suited our needs for power distribution very well since it allowed for a power line to be passed vertically along each stack. Using this orientation, four RPi stacks were assembled and mounted between two pieces of ¼” Plexiglas. This created a solid structure in which the cluster could be housed and maintain physical stability under the combined weight of 32 Ethernet cables. Figure 4 (a) shows some initial experimentation using this method of mounting. The Plexiglas layout for mounting each RPi stack was designed using EagleCAD, along with the power/LED PCB. Figure 4 (b) shows the layout.
| [Figure 4]
There are two methods of powering an RPi. Each RPi has a microUSB port that enables it to be powered from a conventional powered USB port. Using this method would require a microUSB cable and a powered USB port for every RPi in the cluster, which would add a lot more cabling to deal with. It also means that there would be cabling on both sides of the cluster. Alternatively, there is an I/O header on the side of the RPi which contains a 5V pin that can be used to power the board externally. The latter option was chosen as it would also allow for additional customization and control of each node. A custom PCB was created to fit the I/O header to provide power and an RGB LED (since electrical engineers must, of course, have LEDs to show that their project is working). Figure 5 (a) and (b) show the circuit and PCB layouts, respectively.
| [Figure 5]
As seen in Figure 5 (a), aside from a RGB LED and some connectors, there is also a poly fuse (PF1). This was included to maintain short-circuit protection in the event of a board failure. The RPi already has a poly fuse between the USB power connector and the 5V rail. That fuse is bypassed when using the 5V pin to power the board. JP1 provides a 5V interconnect vertically between the RPis in each stack.

With the power being directly distributed via the Power/LED board, it was necessary to find a good source of 5V with sufficient amperage to drive the whole cluster. Each RPi draws about 400mA at 5V (2W), thus we needed a minimum of 13A of 5V (65W) (and more for overclocking). You could, of course, buy a dedicated high output 5V power supply, but a great option is to use a standard PC power supply. PC power supplies are already designed for high loads on their 5V rails, and they are relatively cheap. The 430W Thermaltake (430W combined output for 5V, 12V, etc) we selected is rated to provide 30A at 5V (150W) and cost $36. We opted to purchase two supplies to keep the overall load very low on each and allow for overclocking or future expansion.

## Final Tweaks

As mentioned earlier, the RPi processor supports overclocking. Another noteworthy feature is that the 512MB of RAM is shared by both GPU and CPU, and the amount of RAM reserved for the GPU is configurable. Both of these features are configurable through modification of parameters in /boot/config.txt. After some testing, the whole cluster was set to run in “Turbo Mode” which overclocks the ARM core to 1GHz and sets the other clocks (SDRAM etc..) to 500MHz. The result was a proportional increase in performance (~30%) and power draw. Since the cluster does not require a desktop environment, the GPU RAM reserve was reduced to 48MB. 48MB seems to be the smallest amount of RAM allowed for the GPU on the current version of Arch Linux ARM for the RPi (it wouldn’t boot with anything less).

## Performance

As discussed earlier, the RPiCluster was not built with the intent of creating a HPC platform. However, it is still interesting to see where it ended up, right? There are, of course, many methods for measuring the performance of a cluster. Initially, I did some individual CPU tests comparing various platforms with the RPi. Table 1 shows the specifications of the platforms used for comparison. Each platform was compared on the basis of single core/single thread integer/floating point performance using the GNU arbitrary precision calculator: bc.
[Table 1]
Figure 6 shows the performance of each platform, where the performance is measured in terms of how little time was required to complete the calculation (shorter time is better).
[Figure 6]
Of course, after I published some details of the RPiCluster, everyone wanted to know what kind of MPI parallel performance the RPiCluster has. So, I took some time to get HPL (http://www.netlib.org/benchmark/hpl/index.html) (often used for the TOP500 (http://www.top500.org/) list) working on the RPiCluster to determine overall parallel computing performance. For comparison, I also setup HPL on a single Onyx node (multi-threaded to leverage all the cores). Table 2 shows the resources available and the HPL results after being tuned for peak performance on both platforms. [Table 2]
As is seen in Table 2, the RPiCluster HPL performance is about one quarter that of the BSU cluster node (Onyx). Although, the RPiCluster can solve larger problems due to its greater available RAM.

## Conclusion

Overall, the RPiCluster has successfully fulfilled its purpose. Since completing the build I have moved my dissertation work exclusively to the RPiCluster. I have found performance perfectly acceptable for my simulation needs, and have had the luxury of customizing the cluster software to fit my requirements exactly.

I would like to thank all the guys I work with in the Hartman Systems Integration Laboratory for all their help implementing the cluster design, especially Michael Pook, Vikram Patel, and Corey Warner. Additionally, this project would not have been possible without support from Dr. Sin Ming Loo and the Boise State University (http://boisestate.edu/) Department of Electrical and Computer Engineering. Additional details may be found in my original white paper, found here. (http://coen.boisestate.edu/ece/raspberry-pi/) I also created a video that shows the cluster running an MPI parallel program I developed to blink LEDs: YouTube. (http://youtu.be/i_r3z1jYHAc)

## Figures/Tables

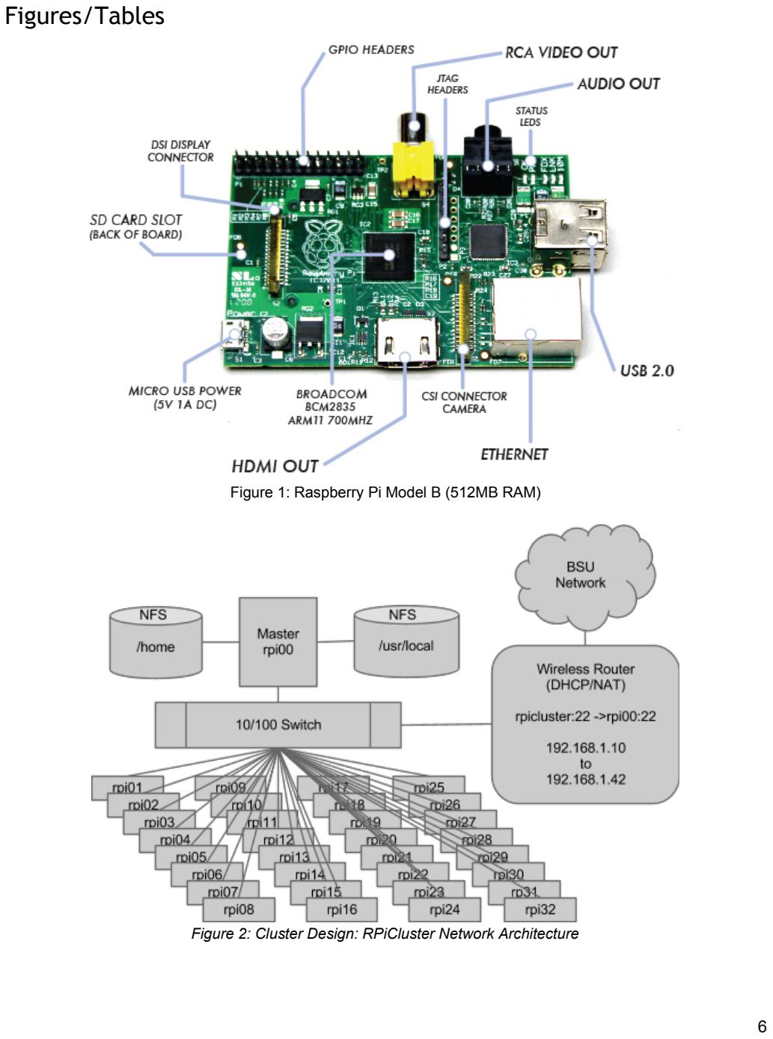
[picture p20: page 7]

Figure 1: Raspberry Pi Model B (512MB RAM)

Figure 2: Cluster Design: RPiCluster Network Architecture

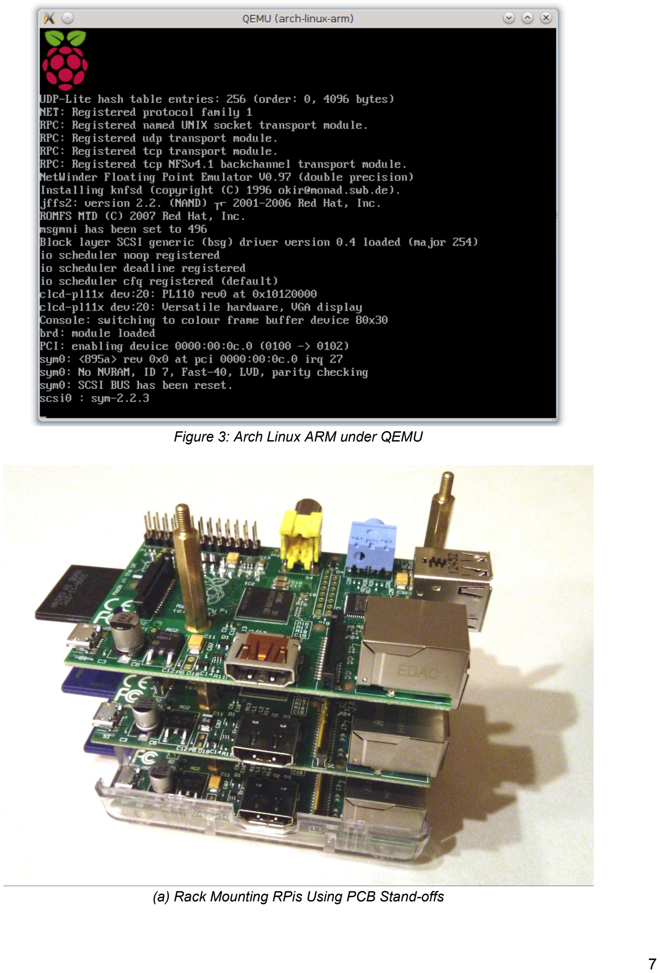
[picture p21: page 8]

Figure 3: Arch Linux ARM under QEMU

(a) Rack Mounting RPis Using PCB Stand-offs

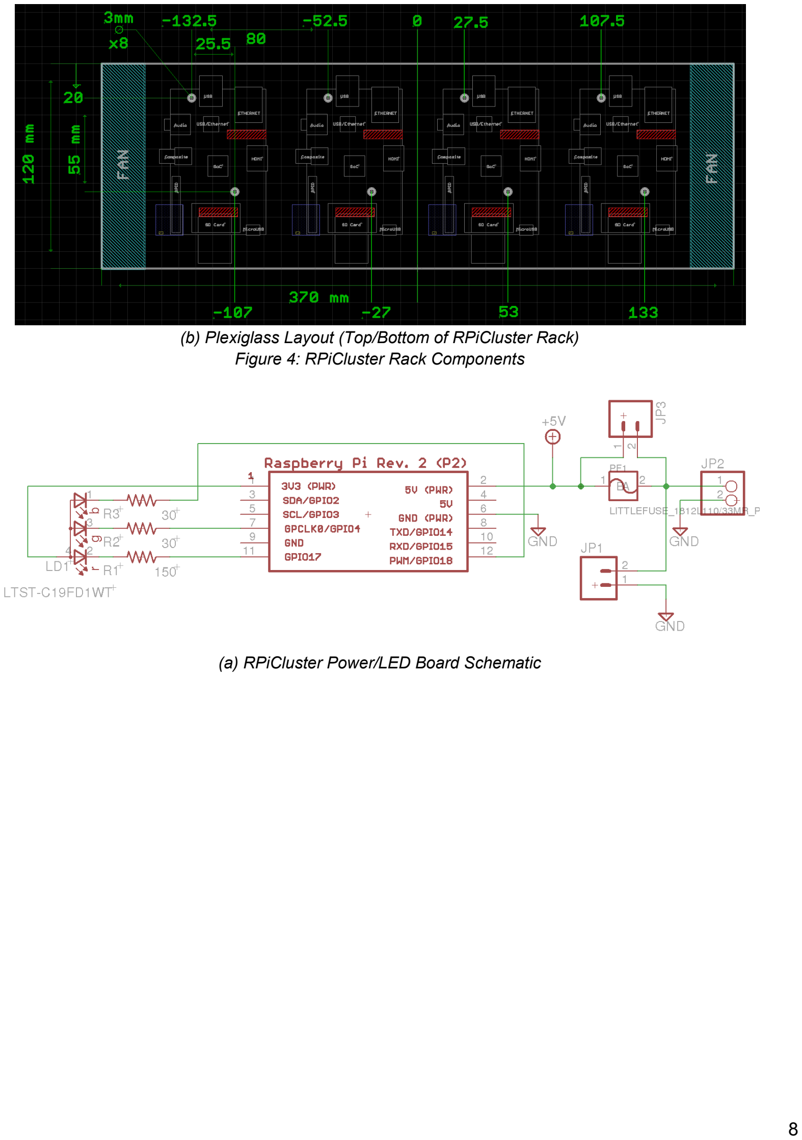
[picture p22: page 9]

(b) Plexiglass Layout (Top/Bottom of RPiCluster Rack) Figure 4: RPiCluster Rack Components
(a) RPiCluster Power/LED Board Schematic


(b) RPiCluster Power/LED Board PCB Layout Figure 5: RPiCluster Power/LED Board

Table 1: Single Core/Single Thread Integer/Floating-Point Platforms

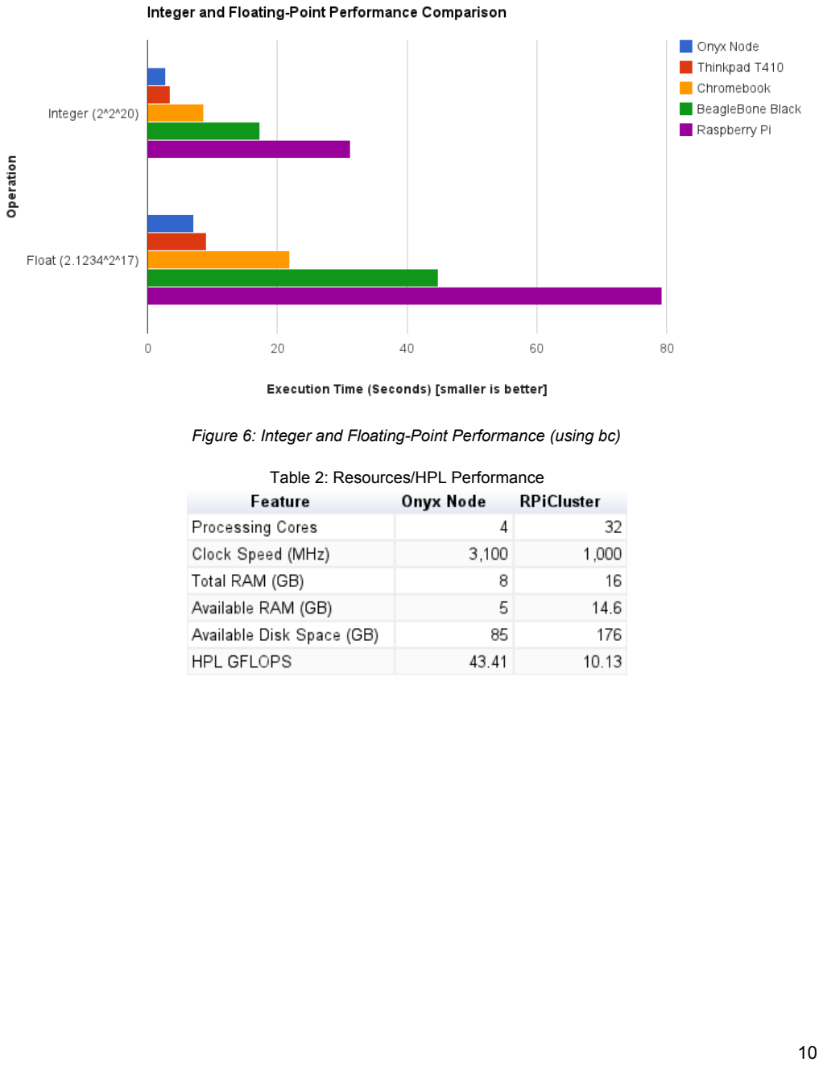
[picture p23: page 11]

Figure 6: Integer and Floating-Point Performance (using bc)

Table 2: Resources/HPL Performance

## Pictures


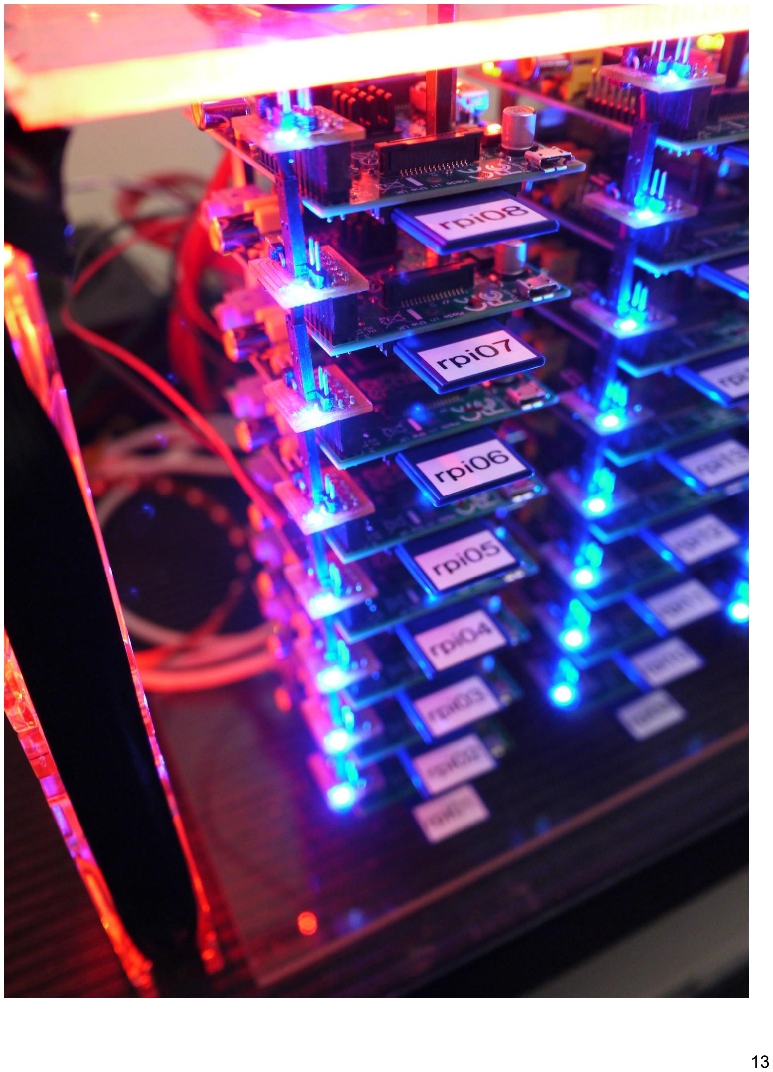
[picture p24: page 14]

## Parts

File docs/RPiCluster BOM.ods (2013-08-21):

Category | Quantity | Description | Supplier | Part Number | Cost | Extended
Computer | 33 | Rasberry Pi Model B | MCM Electronics | 83-14421 (http://www.mcmelectronics.com/product/83-14421) | $35.00 | $1,155.00
Storage | 33 | 8 GB Class 10 SD Card | Amazon | B003VNKNEG (http://www.amazon.com/Transcend-Class-Flash-Memory-TS8GSDHC10E/dp/B003VNKNEG) | $8.79 | $290.07
Rack | 74 | Standoff M/F M3 25mm BB, 33mm OAL | Digi-Key | AE10782-ND (http://www.digikey.com/product-detail/en/R30-3002502/952-1512-ND/2264493) | $0.40 | $29.60
Rack | 8 | HEX NUT 0.217" M3 | Digi-Key | H762-ND (http://www.digikey.com/product-detail/en/MHNZ%20003/H762-ND/274973) | $0.04 | $0.32
Rack | 8 | MACHINE SCREW PAN PHILLIPS M3 | Digi-Key | H744-ND (http://www.digikey.com/product-detail/en/MPMS%20003%200012%20PH/H744-ND/274955) | $0.07 | $0.56
Rack | 16 | WASHER FLAT M3 STEEL | Digi-Key | H767-ND (http://www.digikey.com/product-detail/en/MFWZ%20003/H767-ND/274978) | $0.04 | 0.64
Rack | 2 | Frame to mount stacks securely (15"x5"x1/4" Clear Plexiglass) | N/A
Ethernet Cables | 4 | 3 ft Cat-6 Network Ethernet Patch Cable - Red (Cat6) (Pack of 10) | Amazon | B0049VQ7P8 (http://www.amazon.com/Cat-6-Network-Ethernet-Patch-Cable/dp/B0049VQ7P8?s=electronics) | $16.90 | $67.60
Switch | 1 | Cisco SF200-48 Switch 48 10/100 Ports (Managed) | Amazon | B004GHMU4W (http://www.amazon.com/Cisco-SF200-48-Mini-GBIC-Warranty-Support/dp/B004GHMU4W) | $283.53 | $283.53
Power Breakout | 33 | PTC RESETTABLE 33V 1.10A 1812L | Digi-Key | F3486CT-ND (http://www.digikey.com/product-detail/en/1812L110%2F33MR/F3486CT-ND/2240058) | $0.45 | $14.85
Power Breakout | 33 | Tri-Color LED (LED RGB 605/525/470NM DIFF SMD) | Digi-Key | 160-2022-1-ND (http://www.digikey.com/product-detail/en/LTST-C19FD1WT/160-2022-1-ND/3711419) | $0.28 | $9.24
Lighting | 2 | Red LED Strip 12V (30 LED) 20" | Digi-Key | 365-1503-1-ND (http://www.digikey.com/product-search/en?x=10&y=15&lang=en&site=us&KeyWords=365-1503-1-ND) | $12.29 | $24.58
Power Supply | 2 | Thermaltake TR2 W0070 430W ATX12V (5V@30A) | Newegg | N82E16817153023 (http://www.newegg.com/Product/Product.aspx?Item=N82E16817153023) | $36.00 | $72.00
Cooling | 4 | Rosewill RFA-120-RL 120mm 4 Red LED Case Fan | Amazon | B00552Q8CM (http://www.amazon.com/Rosewill-RFA-120-RL-120mm-Red-Case/dp/B00552Q8CM?s=pc) | $4.99 | $19.96
Total: |  |  |  |  |  | $1,967.95

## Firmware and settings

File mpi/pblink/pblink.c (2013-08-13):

//============================================================================
// Name        : pblink.c
// Description : MPI based system for blinking RGB leds on a cluster of
// 		 Raspberry Pis
// wiringPi pin numbers:
//
//      pin 0 = (Header pin 11) (Red)
//      pin 1 = (Header pin 12) (Blue)
//      pin 2 = (Header pin 13)
//      pin 3 = (Header pin 15)
//      pin 4 = (Header pin 16)
//      pin 5 = (Header pin 18)
//      pin 6 = (Header pin 22)
//      pin 7 = (Header pin 7) (Green)
//
// Author: Joshua Kiepert
// Date: 2013-03-08
// Modified: 2013-05-14
//============================================================================

#include <errno.h>
#include <stdlib.h>
#include <unistd.h>
#include <stdio.h>
#include <mpi.h>
#include <wiringPi.h>
#include <pthread.h>
#include <signal.h>
#include <stdbool.h>

const int R_PIN = 0;
const int B_PIN = 1;
const int G_PIN = 7;
const int OFF = 1;
const int ON = 0;

const int JOB_COMPLETED = 1;
const int CHASE = 2;
const int STROBE = 3;
const int BLINK = 4;

#define NETWORK_LAYOUT

#ifdef NETWORK_LAYOUT
  int stackwise_up[] = {29,25,21,17,13,9,5,1,30,26,22,18,14,10,6,2,31,27,23,19,15,11,7,3,32,28,24,20,16,12,8,4};
  int stackwise_up_size = 32;
  int stackwise_down[] = {1,5,9,13,17,21,25,29,2,6,10,14,18,22,26,30,3,7,11,15,19,23,27,31,4,8,12,16,20,24,28,32};                                                                                                                             
  int stackwise_down_size = 32;
  int horizontal_lr[] = {1,2,3,4,5,6,7,8,9,10,11,12,13,14,15,16,17,18,19,20,21,22,23,24,25,26,27,28,29,30,31,32};                                                                                                                              
  int horizontal_lr_size = 32;
  int horizontal_rl[] = {4,3,2,1,8,7,6,5,12,11,10,9,16,15,14,13,20,19,18,17,24,23,22,21,28,27,26,25,32,31,30,29};
  int horizontal_rl_size = 32;
  int spiral[] = {1,2,3,4,8,12,16,20,24,28,32,31,30,29,25,21,17,13,9,5,6,7,11,15,19,23,27,26,22,18,14,10,11,15,19,18,14,15,19,18};
  int spiral_size = 40;
  int zigzag[] = {1,2,3,4,8,7,6,5,9,10,11,12,16,15,14,13,17,18,19,20,24,23,22,21,25,26,27,28,32,31,30,29};
  int zigzag_size = 32;
  int circle_outer[] = {29,25,21,17,13,9,5,1,2,3,4,8,12,16,20,24,28,32,31,30};
  int circle_outer_size = 20;
  int circle_inner_ccw[] = {7,6,10,14,18,22,26,27,23,19,15,11};
  int circle_inner_ccw_size = 12;
  int circle_inner_cw[] = {7,11,15,19,23,27,26,22,18,14,10,6};  
  int circle_inner_cw_size = 12;

  const int ROW0 = 0x0000000F;
  const int ROW1 = 0x000000F0;
  const int ROW2 = 0x00000F00;
  const int ROW3 = 0x0000F000;
  const int ROW4 = 0x000F0000;
  const int ROW5 = 0x00F00000;
  const int ROW6 = 0x0F000000;
  const int ROW7 = 0xF0000000;
  const int COL0 = 0x11111111;
  const int COL1 = 0x22222222;
  const int COL2 = 0x44444444;
  const int COL3 = 0x88888888;
#else
  int stackwise_up[] = {1,2,3,4,5,6,7,8,9,10,11,12,13,14,15,16,17,18,19,20,21,22,23,24,25,26,27,28,29,30,31,32};      
  int stackwise_up_size = 32;
  int stackwise_down[] = {8,7,6,5,4,3,2,1,16,15,14,13,12,11,10,9,24,23,22,21,20,19,18,17,32,31,30,29,28,27,26,25};       
  int stackwise_down_size = 32;
  int horizontal_lr[] = {8,16,24,32,7,15,23,31,6,14,22,30,5,13,21,29,4,12,20,28,3,11,19,27,2,10,18,26,1,9,17,25};       
  int horizontal_lr_size = 32;
  int horizontal_rl[] = {32,24,16,8,31,23,15,7,30,22,14,6,29,21,13,5,28,20,12,4,27,19,11,3,26,18,10,2,25,17,9,1};       
  int horizontal_rl_size = 32;
  int spiral[] = {8,16,24,32,31,30,29,28,27,26,25,17,9,1,2,3,4,5,6,7,15,23,22,21,20,19,18,10,11,12,13,14,22,21,20,12,13,21,20,12};
  int spiral_size = 40;
  int zigzag[] = {8,16,24,32,31,23,15,7,6,14,22,30,29,21,13,5,4,12,20,28, 27,19,11,3,2,10,18,26,25,17,9,1};
  int zigzag_size = 32;
  int circle_outer[] = {1,2,3,4,5,6,7,8,16,24,32,31,30,29,28,27,26,25,17,9};
  int circle_outer_size = 20;
  int circle_inner_ccw[] = {23,15,14,13,12,11,10,18,19,20,21,22};
  int circle_inner_ccw_size = 12;
  int circle_inner_cw[] = {23,22,21,20,19,18,10,11,12,13,14,15};
  int circle_inner_cw_size = 12;

  const int ROW0 = 0x01010101;
  const int ROW1 = 0x02020202;
  const int ROW2 = 0x04040404;
  const int ROW3 = 0x08080808;
  const int ROW4 = 0x10101010;
  const int ROW5 = 0x20202020;
  const int ROW6 = 0x40404040;
  const int ROW7 = 0x80808080;
  const int COL0 = 0x000000FF;
  const int COL1 = 0x0000FF00;
  const int COL2 = 0x00FF0000;
  const int COL3 = 0xFF000000;
#endif

const int MSK_ALL = 0x7;
const int MSK_R = 0x1;
const int MSK_G = 0x2;
const int MSK_B = 0x4;

struct pstruct {
    int *pattern;
    int pattern_size;
    int me;
    int blinkrate;
    int mask;
    int iterations;
};

static bool Abort = false;

void blink(int rate, int mask) {
    int us = 1000 * rate;

    if ((mask & MSK_R) > 0) {
        digitalWrite(R_PIN, ON);
        usleep(us);
        digitalWrite(R_PIN, OFF);
        usleep(us);
    } else {
        digitalWrite(R_PIN, OFF);
    }

    if ((mask & MSK_G) > 0) {
        digitalWrite(G_PIN, ON);
        usleep(us);
        digitalWrite(G_PIN, OFF);
        usleep(us);
    } else {
        digitalWrite(G_PIN, OFF);
    }

    if ((mask & MSK_B) > 0) {
        digitalWrite(B_PIN, ON);
        usleep(us);
        digitalWrite(B_PIN, OFF);
    } else {
        digitalWrite(B_PIN, OFF);
    }
}

void intHandler(int dummy) {
    Abort = true;
}

void blink_row_column(int me, int brate, int mask, int iterations) {
    int rows[] = {ROW0, ROW1, ROW2, ROW3, ROW4, ROW5, ROW6, ROW7};
    int rows_size = 8;
    int columns[] = {COL0, COL1, COL2, COL3};
    int columns_size = 4;
    int root = 0;
    bool done = false;
    bool timed = true;
    int countdown = iterations;
    bool keepRunning = true;
    int blinkrate = brate;
    int data[2];
    int delayms = 6;

    MPI_Barrier(MPI_COMM_WORLD);

    if (me == 0) {

        if (iterations < 0) {
            timed = false;
        }

        while (1) {
            if (timed) {
                if (countdown == 0) {
                    keepRunning = false;
                } else {
                    countdown--;
                }
            }

            if (!keepRunning || Abort) {
                if (done) {
                    return;
                } else {
                    blinkrate = -1;
                    done = true;
                }
            }

            if (blinkrate > 0) {
                for (int i = 0; i < rows_size; i++) {
                    data[0] = blinkrate;
                    data[1] = rows[i];
                    MPI_Bcast(data, 2, MPI_INT, root, MPI_COMM_WORLD);

                    if (blinkrate > 0)
                        usleep(1000 * blinkrate * delayms);
                }


                for (int i = rows_size - 1; i > -1; i--) {
                    data[0] = blinkrate;
                    data[1] = rows[i];
                    MPI_Bcast(data, 2, MPI_INT, root, MPI_COMM_WORLD);

                    if (blinkrate > 0)
                        usleep(1000 * blinkrate * delayms);
                }


                for (int i = 0; i < columns_size; i++) {
                    data[0] = blinkrate;
                    data[1] = columns[i];

                    MPI_Bcast(data, 2, MPI_INT, root, MPI_COMM_WORLD);

                    if (blinkrate > 0)
                        usleep(1000 * blinkrate * delayms);
                }


                for (int i = columns_size - 1; i > -1; i--) {
                    data[0] = blinkrate;
                    data[1] = columns[i];

                    MPI_Bcast(data, 2, MPI_INT, root, MPI_COMM_WORLD);

                    if (blinkrate > 0)
                        usleep(1000 * blinkrate * delayms);
                }
            } else {
                data[0] = blinkrate;
                data[1] = 0;
                MPI_Bcast(data, 2, MPI_INT, root, MPI_COMM_WORLD);
            }
        }
    } else {
        while (1) {
            MPI_Bcast(data, 2, MPI_INT, root, MPI_COMM_WORLD);

            if (data[0] < 0) {
                return;
            }

            if (data[1] & (1 << (me - 1))) {
                blink(data[0], mask);
            }
        }
    }

}

void blink_all(int me, int brate, int mask, int iterations) {
    int root = 0;
    bool done = false;
    bool timed = true;
    int countdown = iterations;
    bool keepRunning = true;
    int blinkrate = brate;

    MPI_Barrier(MPI_COMM_WORLD);

    if (me == 0) {

        if (iterations < 0) {
            timed = false;
        }

        while (1) {
            if (timed) {
                if (countdown == 0) {
                    keepRunning = false;
                } else {
                    countdown--;
                }
            }

            if (!keepRunning || Abort) {
                if (done) {
                    return;
                } else {
                    blinkrate = -1;
                    done = true;
                }
            }

            MPI_Bcast(&blinkrate, 1, MPI_INT, root, MPI_COMM_WORLD);

            if (blinkrate > 0)
                usleep(1000 * blinkrate * 5);
        }
    } else {
        while (1) {
            MPI_Bcast(&blinkrate, 1, MPI_INT, root, MPI_COMM_WORLD);

            if (blinkrate < 0) {
                return;
            }

            blink(blinkrate, mask);
        }
    }
}

void chase(int me, int *pattern, int pattern_size, int brate, int mask, int iterations) {
    bool done = false;
    bool timed = true;
    int countdown = iterations;
    bool keepRunning = true;
    int blinkrate = brate;
    MPI_Status status;
    int who;

    MPI_Barrier(MPI_COMM_WORLD);

    if (me == 0) {

        if (iterations < 0) {
            timed = false;
        }

        while (1) {
            if (timed) {
                if (countdown == 0) {
                    keepRunning = false;
                } else {
                    countdown--;
                }
            }

            if (!keepRunning || Abort) {
                if (done) {
                    return;
                } else {
                    blinkrate = -1;
                    done = true;
                }
            }

            for (int i = 0; i < pattern_size; i++) {
                MPI_Send(&blinkrate, 1, MPI_INT, pattern[i], CHASE, MPI_COMM_WORLD);
                MPI_Recv(&who, 1, MPI_INT, pattern[i], CHASE, MPI_COMM_WORLD, &status);
            }
        }
    } else {
        while (1) {
            MPI_Recv(&blinkrate, 1, MPI_INT, 0, CHASE, MPI_COMM_WORLD, &status);
            if (blinkrate < 0) {
                MPI_Send(&me, 1, MPI_INT, 0, CHASE, MPI_COMM_WORLD);
                return;
            } else {
                blink(blinkrate, mask);
                MPI_Send(&me, 1, MPI_INT, 0, CHASE, MPI_COMM_WORLD);
            }
        }
    }
}

void strobe(int me, int *pattern, int pattern_size, int brate, int mask, int iterations) {
    bool done = false;
    bool timed = true;
    int countdown = iterations;
    bool keepRunning = true;
    int blinkrate = brate;
    MPI_Status status;

    MPI_Barrier(MPI_COMM_WORLD);

    if (me == 0) {
        if (iterations < 0) {
            timed = false;
        }

        while (1) {
            if (timed) {
                if (countdown == 0) {
                    keepRunning = false;
                } else {
                    countdown--;
                }
            }

            if (!keepRunning || Abort) {
                if (done) {
                    return;
                } else {
                    blinkrate = -1;
                    done = true;
                }
            }

            if (blinkrate > 0) {
                for (int i = 0; i < pattern_size; i++) {
                    MPI_Send(&blinkrate, 1, MPI_INT, pattern[i], STROBE, MPI_COMM_WORLD);

                    if (blinkrate > 0) {
                        usleep(1000 * blinkrate);
                    } else {
                        usleep(1000);
                    }
                }
            } else {
                for (int i = 0; i < stackwise_up_size; i++) {
                    MPI_Send(&blinkrate, 1, MPI_INT, stackwise_up[i], STROBE, MPI_COMM_WORLD);
                }
            }
        }
    } else {
        while (1) {
            MPI_Recv(&blinkrate, 1, MPI_INT, 0, STROBE, MPI_COMM_WORLD, &status);

            if (blinkrate < 0) {
                return;
            }

            blink(blinkrate, mask);
        }
    }
}

void *threaded_strobe(void *pattern_struct) {
    struct pstruct *p = (struct pstruct*) pattern_struct;
    strobe(p->me, p->pattern, p->pattern_size, p->blinkrate, p->mask, p->iterations);
    return NULL;
}

void multistrobe(int me, int *pattern1, int pattern1_size, int *pattern2, int pattern2_size, int brate, int mask, int iterations) {
    static struct pstruct pstruct_inner;
    static struct pstruct pstruct_outer;
    int blinkrate = brate;
    MPI_Status status;

    pthread_t outerThread, innerThread;
    pstruct_inner.me = me;
    pstruct_inner.pattern = pattern2;
    pstruct_inner.pattern_size = pattern2_size;
    pstruct_inner.blinkrate = blinkrate << 2;
    pstruct_inner.iterations = iterations;
    pstruct_inner.mask = mask;
    pstruct_outer.me = me;
    pstruct_outer.pattern = pattern1;
    pstruct_outer.pattern_size = pattern1_size;
    pstruct_outer.blinkrate = blinkrate;
    pstruct_outer.iterations = iterations;
    pstruct_outer.mask = mask;

    if (me == 0) {
        usleep(1000 * blinkrate);
        pthread_create(&outerThread, NULL, threaded_strobe, (void*) &pstruct_outer);
        usleep(1000 * blinkrate);
        pthread_create(&innerThread, NULL, threaded_strobe, (void*) &pstruct_inner);

        pthread_join(outerThread, NULL);
        pthread_join(innerThread, NULL);

    } else {
        while (1) {
            MPI_Recv(&blinkrate, 1, MPI_INT, 0, JOB_COMPLETED, MPI_COMM_WORLD, &status);

            if (blinkrate < 0) {
                return;
            }

            blink(blinkrate, mask);
        }
    }
}

void run(int me, int mode, int brate, int mask, int iterations) {
    int msk = mask;
    int i = 0;

    switch (mode) {
        case 0:
            chase(me, stackwise_up, stackwise_up_size, brate, mask, iterations);
            break;
        case 1:
            chase(me, stackwise_down, stackwise_down_size, brate, mask, iterations);
            break;
        case 2:
            chase(me, horizontal_lr, horizontal_lr_size, brate, mask, iterations);
            break;
        case 3:
            chase(me, horizontal_rl, horizontal_rl_size, brate, mask, iterations);
            break;
        case 4:
            chase(me, spiral, spiral_size, brate, mask, iterations);
            break;
        case 5:
            chase(me, zigzag, zigzag_size, brate, mask, iterations);
            break;
        case 6:
            strobe(me, stackwise_up, stackwise_up_size, brate, mask, iterations);
            break;
        case 7:
            strobe(me, stackwise_down, stackwise_down_size, brate, mask, iterations);
            break;
        case 8:
            strobe(me, horizontal_lr, horizontal_lr_size, brate, mask, iterations);
            break;
        case 9:
            strobe(me, horizontal_rl, horizontal_rl_size, brate, mask, iterations);
            break;
        case 10:
            strobe(me, spiral, spiral_size, brate, mask, iterations);
            break;
        case 11:
            strobe(me, zigzag, zigzag_size, brate, mask, iterations);
            break;
        case 12:
            blink_all(me, brate, mask, iterations);
            break;
        case 13:
            multistrobe(me, circle_outer, circle_outer_size, circle_inner_ccw, circle_inner_ccw_size, brate, mask, iterations);
            break;
        case 14:
            blink_row_column(me, brate, mask, iterations);
            break;
        default:

            if (me == 0) {
                printf("Running all...\r\n");
                fflush(stdout);
            }

            while (!Abort) {

                if (!Abort) chase(me, stackwise_up, stackwise_up_size, brate, msk, iterations);
                if (!Abort) strobe(me, stackwise_up, stackwise_up_size, brate, msk, iterations);
                if (!Abort) strobe(me, stackwise_down, stackwise_down_size, brate, msk, iterations);
                if (!Abort) strobe(me, horizontal_lr, horizontal_lr_size, brate, msk, iterations);
                if (!Abort) strobe(me, horizontal_rl, horizontal_rl_size, brate, msk, iterations);
                if (!Abort) strobe(me, spiral, spiral_size, brate, msk, iterations);
                if (!Abort) blink_all(me, brate, MSK_R, iterations * 7);
                if (!Abort) blink_all(me, brate, MSK_G, iterations * 7);
                if (!Abort) blink_all(me, brate, MSK_B, iterations * 7);
                if (!Abort) blink_all(me, brate, MSK_ALL, iterations * 7);
                if (!Abort) blink_row_column(me, brate / 2, msk, iterations);

                switch (i) {
                    case(0):
                        msk = MSK_R;
                        break;
                    case(1):
                        msk = MSK_G;
                        break;
                    case(2):
                        msk = MSK_B;
                        break;
                    default:
                        msk = mask;
                }

                i = (i + 1) % 4;
            }
    }

    digitalWrite(R_PIN, OFF);
    digitalWrite(G_PIN, OFF);
    digitalWrite(B_PIN, OFF);

    return;
}

int main(int argc, char **argv) {
    double timeStart = 0;
    double timeElapsed = 0;
    int iterations = -1;
    int blinkrate = 100;
    int mode = 12;
    int me;
    int nproc;
    int mask = MSK_ALL;

    if (argc < 2) {
        fprintf(stderr, "Usage: sudo %s <blink rate (ms)> [mode] [iterations] [mask]\n", argv[0]);
        exit(1);
    }

    sscanf(argv[1], "%d", &blinkrate);

    if (argc >= 3) {
        sscanf(argv[2], "%d", &mode);
    }

    if (argc >= 4) {
        sscanf(argv[3], "%d", &iterations);
    }

    if (argc == 5) {
        sscanf(argv[4], "%d", &mask);
    }

    MPI_Init(&argc, &argv);
    MPI_Comm_size(MPI_COMM_WORLD, &nproc);
    MPI_Comm_rank(MPI_COMM_WORLD, &me);

    if (wiringPiSetup() == -1) {
        printf("Error opening GPIO!\n");
        fflush(stdout);
        exit(1);
    }

    pinMode(R_PIN, OUTPUT);
    digitalWrite(R_PIN, OFF);
    pinMode(G_PIN, OUTPUT);
    digitalWrite(R_PIN, OFF);
    pinMode(B_PIN, OUTPUT);
    digitalWrite(R_PIN, OFF);

    if (me == 0) {
        timeStart = MPI_Wtime();

    }

    signal(SIGINT, intHandler);

    if (me == 0) {
        printf("Blinking at %d ms on %d processors...\n", blinkrate, nproc);
        printf("Set mode: %d\n", mode);
        printf("Set iterations: %d\n", iterations);
        fflush(stdout);
    }

    run(me, mode, blinkrate, mask, iterations);

    if (me == 0) {
        timeElapsed = MPI_Wtime() - timeStart;
        printf("Elapsed time:  %lf seconds\n", timeElapsed);
        fflush(stdout);
    }

    MPI_Finalize();
    exit(0);
}

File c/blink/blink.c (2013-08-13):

//============================================================================
// Name         : blink.c
// Author       : Josh Kiepert
// Description  : C WiringPi based routing for blinking an RGB LED
//                Raspberry Pis
//
//  wiringPi pin numbers:
//  pin 0 = (Header pin 11) (Red)
//  pin 1 = (Header pin 12) (Blue)
//  pin 2 = (Header pin 13)
//  pin 3 = (Header pin 15)
//  pin 4 = (Header pin 16)
//  pin 5 = (Header pin 18)
//  pin 6 = (Header pin 22)
//  pin 7 = (Header pin 7)  (Green)
//
// Author       : Joshua Kiepert
// Date         : 2013-03-08
//============================================================================

#include <errno.h>
#include <stdlib.h>
#include <unistd.h>
#include <stdio.h>
#include <wiringPi.h>
#include <pthread.h>
#include <signal.h>
#include <stdbool.h>
#include <stdint.h>

const int R_PIN = 0;
const int B_PIN = 1;
const int G_PIN = 7;
const int R_MSK = 0x1;
const int B_MSK = 0x2;
const int G_MSK = 0x4;

const int OFF = 1;
const int ON = 0;

static bool keepRunning = true;

void intHandler(int dummy){
  keepRunning = false;  
}

bool timeout(int *countdown){
  bool timed = true;
  
  if(*countdown < 0){
    timed = false;
  }
  
  if(timed){
    if(*countdown == 0){
      keepRunning = false;
    }else{
      printf("\rTimeout in: %5d", *countdown);
      fflush(stdout);
      (*countdown)--;
    }
  }
  
  if(!keepRunning){
    printf("\n");
    fflush(stdout);
    return true;
  }
  
  return false;
}

void led_set(uint8_t mask){
  
  if(mask & R_MSK){
    digitalWrite(R_PIN,ON);
  }else{
    digitalWrite(R_PIN,OFF);
  }
  
  if(mask & B_MSK){
    digitalWrite(B_PIN,ON);
  }else{
    digitalWrite(B_PIN,OFF);
  }
  
  if(mask & G_MSK){
    digitalWrite(G_PIN,ON);
  }else{
    digitalWrite(G_PIN,OFF);
  }
}

void led_toggle(uint8_t mask){
  int state = 0;
  
  if(mask & R_MSK){
    state = digitalRead(R_PIN);
    digitalWrite(R_PIN,state ^ 1);
  }else{
    digitalWrite(R_PIN,OFF);
  }
  
  if(mask & G_MSK){
    state = digitalRead(G_PIN);
    digitalWrite(G_PIN,state ^ 1);
  }else{
    digitalWrite(G_PIN,OFF);
  }
  
  if(mask & B_MSK){
    state = digitalRead(B_PIN);
    digitalWrite(B_PIN,state ^ 1);
  }else{
    digitalWrite(B_PIN,OFF);
  }
}

void blink(int mask, int rate){
  int us = 1000*rate;
  
  if(mask & R_MSK){
    digitalWrite(R_PIN,ON);
    usleep(us);
    digitalWrite(R_PIN,OFF);
    usleep(us);
  }else{
    digitalWrite(R_PIN,OFF);
  }
  
  if(mask & G_MSK){
    digitalWrite(G_PIN,ON);
    usleep(us);
    digitalWrite(G_PIN,OFF);
    usleep(us);
  }else{
    digitalWrite(G_PIN,OFF);
  }
  
  if(mask & B_MSK){
    digitalWrite(B_PIN,ON);
    usleep(us);
    digitalWrite(B_PIN,OFF);
    usleep(us);
  }else{
    digitalWrite(B_PIN,OFF);
  }
  
}

void led_setter(int mask, int ms){
  static int countdown = -1;
  countdown = ms;
  
  led_set(mask);
  
  while(!timeout(&countdown)){   
    usleep(1000);
  }
}

void led_toggler(int mask, int rate, int iterations){
  static int countdown = -1;
  int ms = 1000*rate;
  
  countdown = iterations;  
  
  while(!timeout(&countdown)){
    led_toggle(mask);
    usleep(ms);
  }
}

void led_blinker(int mask, int rate, int iterations){
  static int countdown = -1;
  countdown = iterations;
  
  while(!timeout(&countdown)){
    blink(mask, rate);
  }
}

void run(int mode, int mask, int rate, int iterations){
  
  switch(mode){
    case 1:
      printf("Mode: %d (constant), mask: %d, iterations(ms): %d\n", mode, mask, iterations);
      fflush(stdout); 
      led_setter(mask, iterations);
      break;
    case 2:
      printf("Mode: %d (toggle), rate: %d, mask: %d, iterations: %d\n", mode, rate, mask, iterations);
      fflush(stdout); 
      led_toggler(mask, rate, iterations);
    default:
      printf("Mode: %d (blink), rate: %d, mask: %d, iterations: %d\n", mode, rate, mask, iterations);
      fflush(stdout); 
      led_blinker(mask, rate, iterations);
      break;
  }
  
  digitalWrite(R_PIN,OFF);
  digitalWrite(G_PIN,OFF);
  digitalWrite(B_PIN,OFF);
  
  return;
}

void usage(char *progname){
  fprintf(stdout, "Usage: %s [mode] [mask] [iterations] [blinkrate]\n" , progname);
}

int main(int argc, char **argv)
{
  static int blinkrate = 50;
  static int mode = 3;
  static int mask = 0x7;
  static int iterations = -1;
  int valid = 0;
  
  if (argc > 5) {
    usage(argv[0]);
    exit(1);
  }
  
  if(argc >= 2){
    valid = sscanf(argv[1],"%d",&mode);
    if(!valid){
      usage(argv[0]);
      exit(1);
    }
  }
  
  if(argc >= 3){
    valid = sscanf(argv[2],"%d",&mask);
     if(!valid){
      usage(argv[0]);
      exit(1);
    }
  }
  
  if(argc >= 4){
    valid = sscanf(argv[3],"%d",&iterations);
    if(!valid){
      usage(argv[0]);
      exit(1);
    }
  }
  
  if(argc == 5){
    valid = sscanf(argv[4],"%d",&blinkrate);
    if(!valid){
      usage(argv[0]);
      exit(1);
    }
  }
    
  if (wiringPiSetup() == -1){
    printf("Error opening GPIO!\n");
    fflush(stdout);
    exit (1);
  }
  
  pinMode(R_PIN, OUTPUT);
  digitalWrite(R_PIN,OFF);
  pinMode(G_PIN, OUTPUT);
  digitalWrite(R_PIN,OFF);
  pinMode(B_PIN, OUTPUT);
  digitalWrite(R_PIN,OFF);
  
  signal(SIGINT, intHandler);
  
  run(mode, mask, blinkrate, iterations);
  
  exit(0);
}

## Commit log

2013-08-13 Initial import of RPiCluster resources.
    [RPiCluster-Case-Layout.brd, RPiCluster-Case-Layout.sch, RPiCluster-Power-LED.brd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]
2013-08-21 Updated LED-Power board schematics/PCB to the latest design
    [RPiCluster-Power-LED.brd, RPiCluster-Power-LED.sch]
2013-08-21 Added BOM
    [RPiCluster BOM.ods]
2013-08-21 Added EagleCAD BOM
